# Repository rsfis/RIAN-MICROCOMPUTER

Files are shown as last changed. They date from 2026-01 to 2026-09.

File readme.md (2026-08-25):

<h1 align="center">
  Fiscion Razor32
</h1>
<h3 align="center">
  A Mini Foldable OldStyle Computer
</h3>

<h3 align="center">
  Being only 14x6x5cm, Razor32 is a complete computer with Firmware, OS and Apps.
</h3>

## Features
- Powered by ESP32 S3 Chip with 8mb RAM and 16mb Flash
- Embedded TFT Screen
- 30 keys Matricial Keyboard. Each key has X and Y push up output
- 3000mah Rechargeable Battery
- Foldable Case Easy and Light to Carry
- USB C charging port
- Easy to assemble
- Custom Firmware and OS
- Runs LUA for Apps
- Easy to create your own apps in a Inside IDE and share them within a local network

## Case
Designed using Blender, the Case comes with 4 parts: The lower box, upper box, hinges and screws. Made using PLA material.
showcase
showcase2

## PCB
The PCBs were made using KiCad. The board contains the sockets for esp32 and screen and a 3x10 matricial keyboard using push buttons.


F.Cu

In.1.Cu

In.2.Cu

B.Cu

3D render front


3D render back



Schematic


#### External Wiring Diagram
wiring diagram

## BOM
|FIELD1|Designator |Quantity|Comment |Link |ENTIRE PRICE WITH FREIGHT AND TAXES:|FIELD7|FIELD8|FIELD9|
|---|---|---|---|---|---|---|---|---|
|1 |TFT Screen 3.5" st7796 320*480 ips |1 |TFT Screen 3.5" st7796 320*480 ips Touch |https://pt.aliexpress.com/item/1005005995931721.html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 |R$ 90,84 | | | |
|2 |ESP32 S3 8mb PSRAM 16mb Flash |1 |ESP32-S3-DevKitC-1 |https://pt.aliexpress.com/item/1005007215982839.html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 |R$ 63,38 | | | |
|3 |Aliexpress parts |1 |Pin Headers 1x15 and 1x6; Flat Cable Socket Bottom Connector 14pins; Screws M3x6mm Allen; Push Buttons 6x6x5mm|(Cart image at repo: cart/aliexpress.png) |R$ 129,76 | | | |
|4 |3D Print |2 |3D Print Case |~ |~ | | | |
|5 |PCB |5 |PCB Manufacture Process |~ |$36,35 | | |PRICE |
|6 |Battery 3.7v 3000mah |1 |Battery 3000mah 3.7v |https://www.mercadolivre.com.br/1-unidade-505573-2-fios-3000mah-37v-5mm-x-55mm-x-73mm/p/MLB2081347995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 |$12,00 | |R$ |552,13|
|7 |Battery Charger Module and Step Up Conversor|1 |Battery Charger Module and Step Up 3.7v to 5v Conversor |https://www.mercadolivre.com.br/carregador-bateria-de-litio-5v-2a-conversor-step-up-usb-c/p/MLB2071876811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|$3,42 | |USD |106,59|

## Keyboard Keys Organization
q w e r t y u i o p

a s d f g h j k l B

z x c v b S n m f E

1 2 3 4 5 6 7 8 9 0

+ - % < > ? & ! ( )

/ * = " _ ; . , f Sh

ESC F1 F2 F3 F4 F5 F6 F7 F8 F9

{    }  @ :  [  ]  

|    \  ' -  HOME

## OS and APPS
The OS is the RazorOS, made using ArduinoIDE, LovyanGFX and LUA Interpreter.

The OS itself is programmed in C++ using Arduino IDE, with own firmware. The OS has:
- Home Page with a Desktop area
- Control Panel for Rapid Settings
- Users
- Clock
- Settings
- Task Manager
- Notifications
- Watchdog
- Terminal in LUA

The apps are made in LUA. Apps will create a LUA Virtual Machine to execute the code directly in the processor using various C++ External Functions. 

Using the Text Editor, you will also be able to create your own apps to Razor32 and control everything.

Planned Apps:
- Internet Browser Based on Text (Lynx)
- File Sender

- Text Editor
- Calculator
- To-do
- Calendar
- PDF Viewer
- Excel Like

- Tetris
- Snake

- Scanner Wifi
- Terminal Serial
- Packet Logger

OS and Firmware are still being programmed. For now, RazorOS already has basic drawing and OS functions and Lua VM implemented.

## Cart
jlc
aliexpress

## Getting Started
### How to flash the ESP32:
- Install ArduinoIDE
- Install the following libraries:
-- LovyanGFX, by lovyan03
-- ArduinoJSON, by BenoitBlanchon
- Install the following Board Managers:
-- esp32, by Espressif Systems
-- Select the COM and board 4D Systems gen4-ESP32 Modules (ESP32-S3)
### Extract the files from /firmware/MicroSD Backup.rar
- Copy the files from /firmware/MicroSD Backup.rar to the microsd root directory
- Insert the micro sd in the MicroSD socket below the screen

Made for: Hackclub FORGE - https://forge.hackclub.com/projects/457

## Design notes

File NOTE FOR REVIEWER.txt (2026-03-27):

The "CAD" was not made in a real CAD software, because I didn't know it was supposed to be. It was made in Blender, so, to provide a .step and CAD file, inside "case" there is a Design.FCStd (.obj imported in CAD).

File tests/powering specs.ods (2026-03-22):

 | ESP32 | TFT SCREEN | TOTAL
ACTIVE CONSUMPTION | 90,00 mA | 95,00 mA | 185,00 mA
SLEEPING CONSUMPTION | 0,24 mA | 10,00 mA | 10,24 mA
 | BATTERY | BATTERY CONVERTED
TENSION | 3,7 V | 5,0 V
CAPACITY | 5000,0 mA | 5000,0 mA
 | ACTIVE | SLEEPING
DURATION (HOURS) | 27,0h | 488,3h
DURATION (DAYS) | 1,1d | 20,3d

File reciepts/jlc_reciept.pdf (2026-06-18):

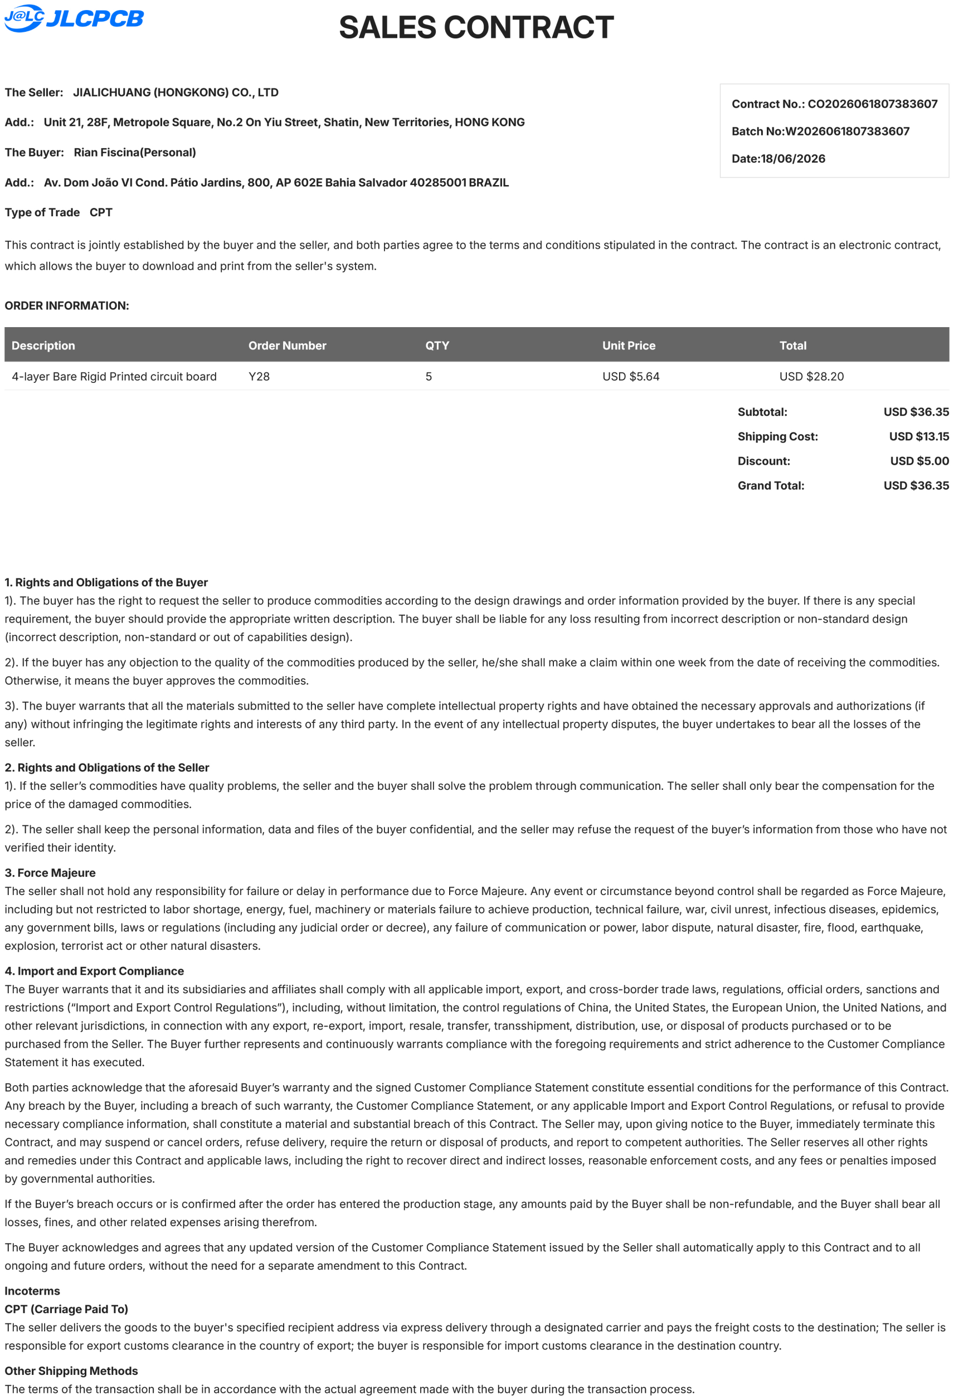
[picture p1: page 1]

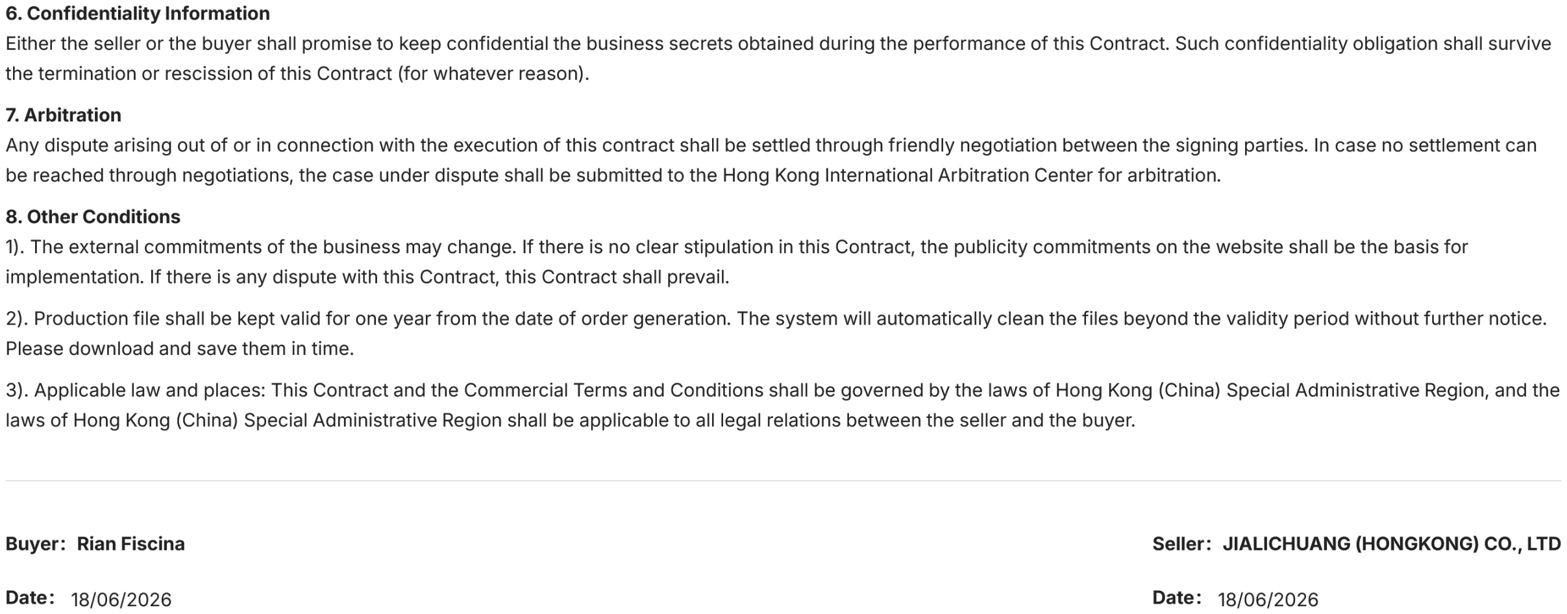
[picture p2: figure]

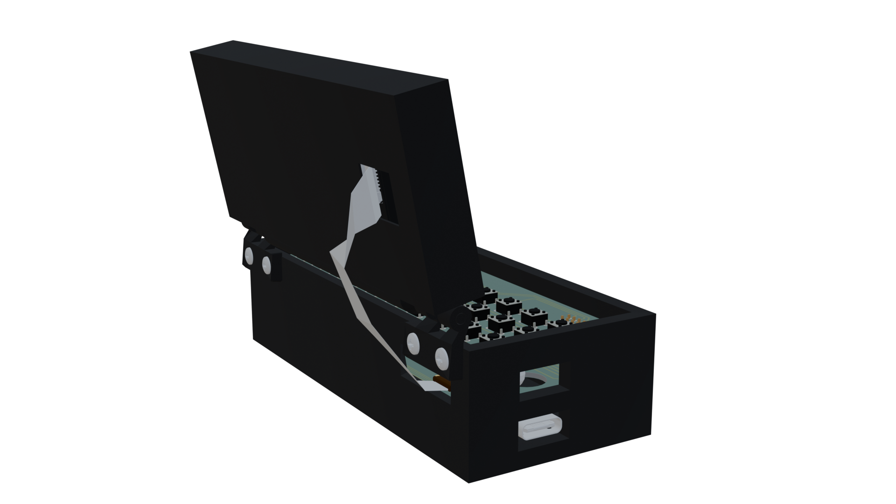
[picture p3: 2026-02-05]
images/showcase2.png

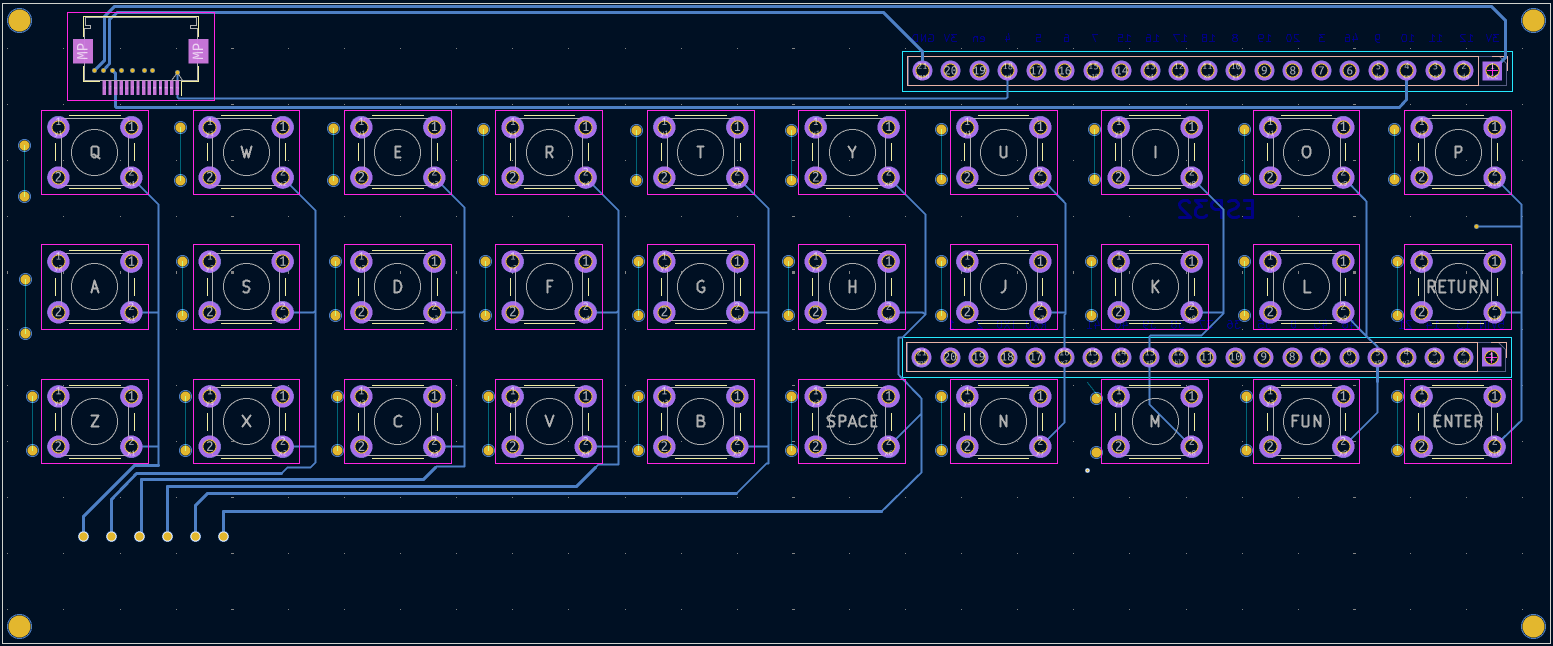
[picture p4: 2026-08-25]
unified pcb/imgs/b_cu.png

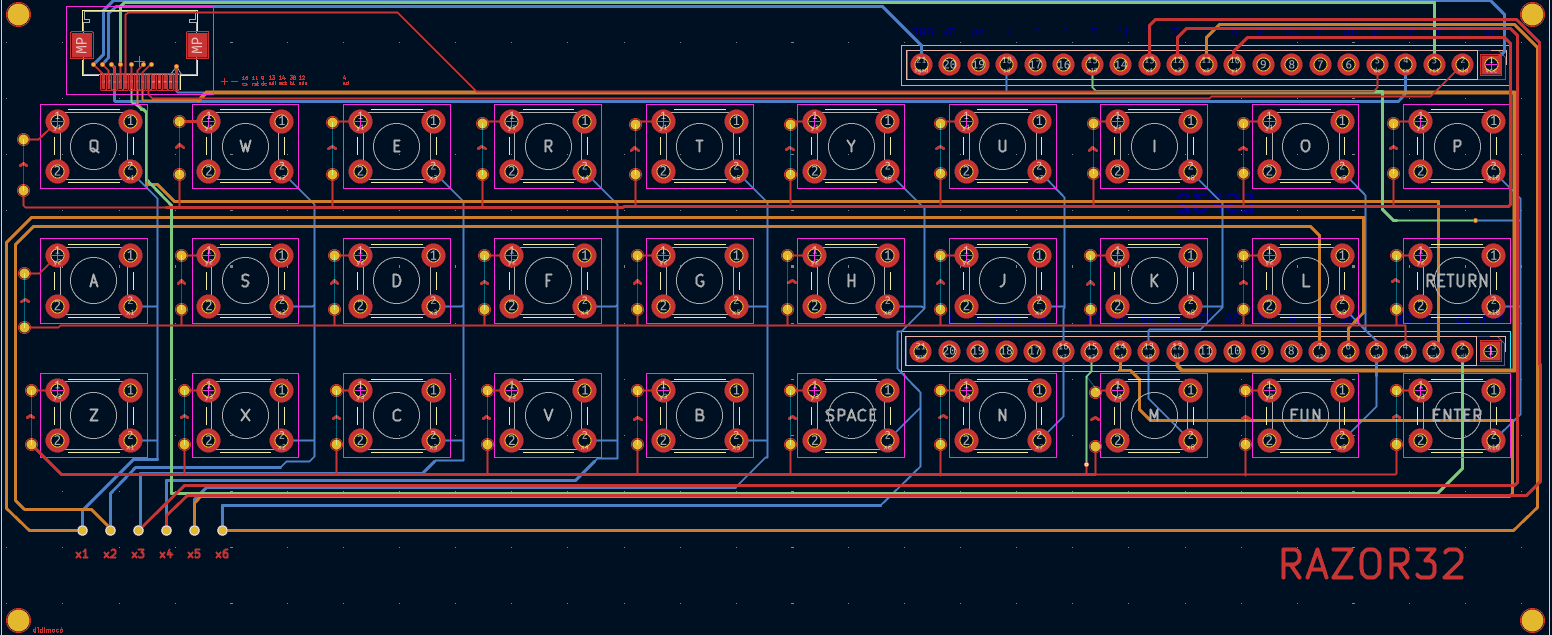
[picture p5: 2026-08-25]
unified pcb/imgs/all.png

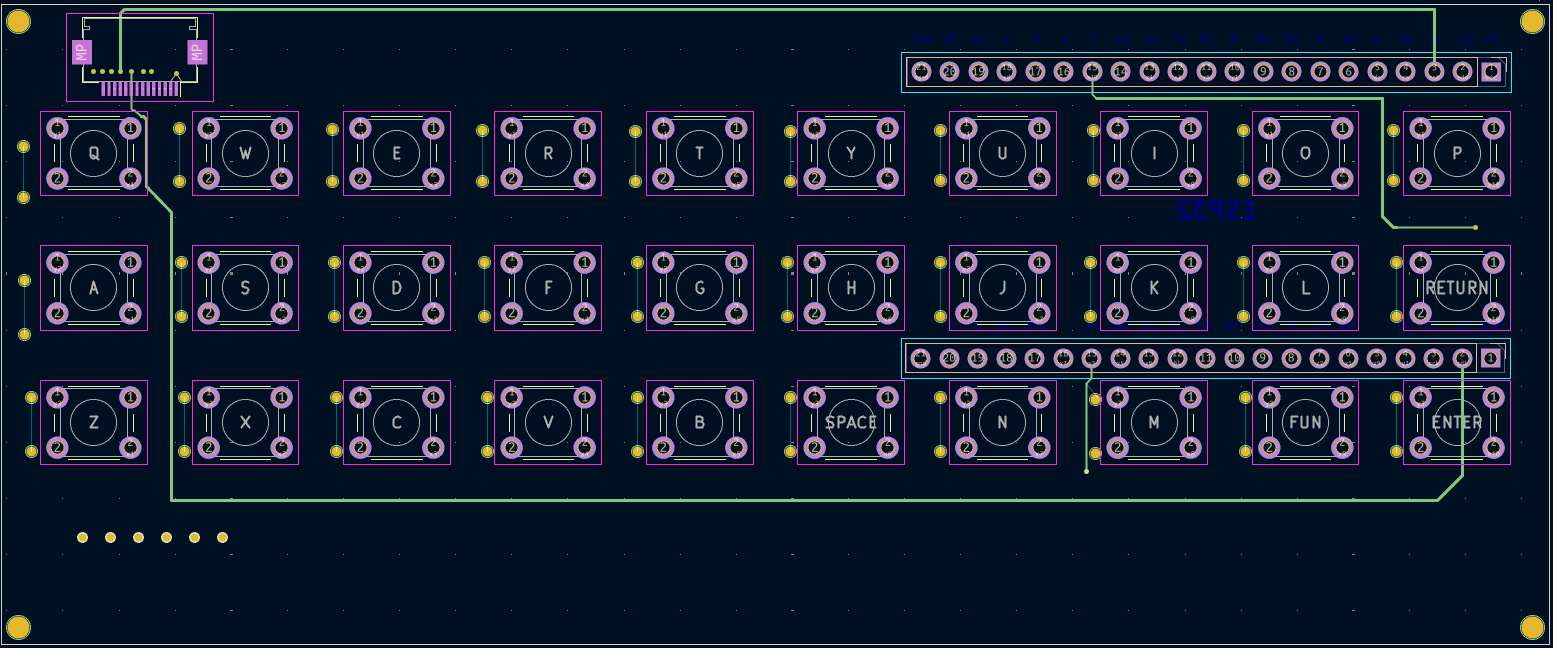
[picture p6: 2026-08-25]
unified pcb/imgs/in1_cu.png

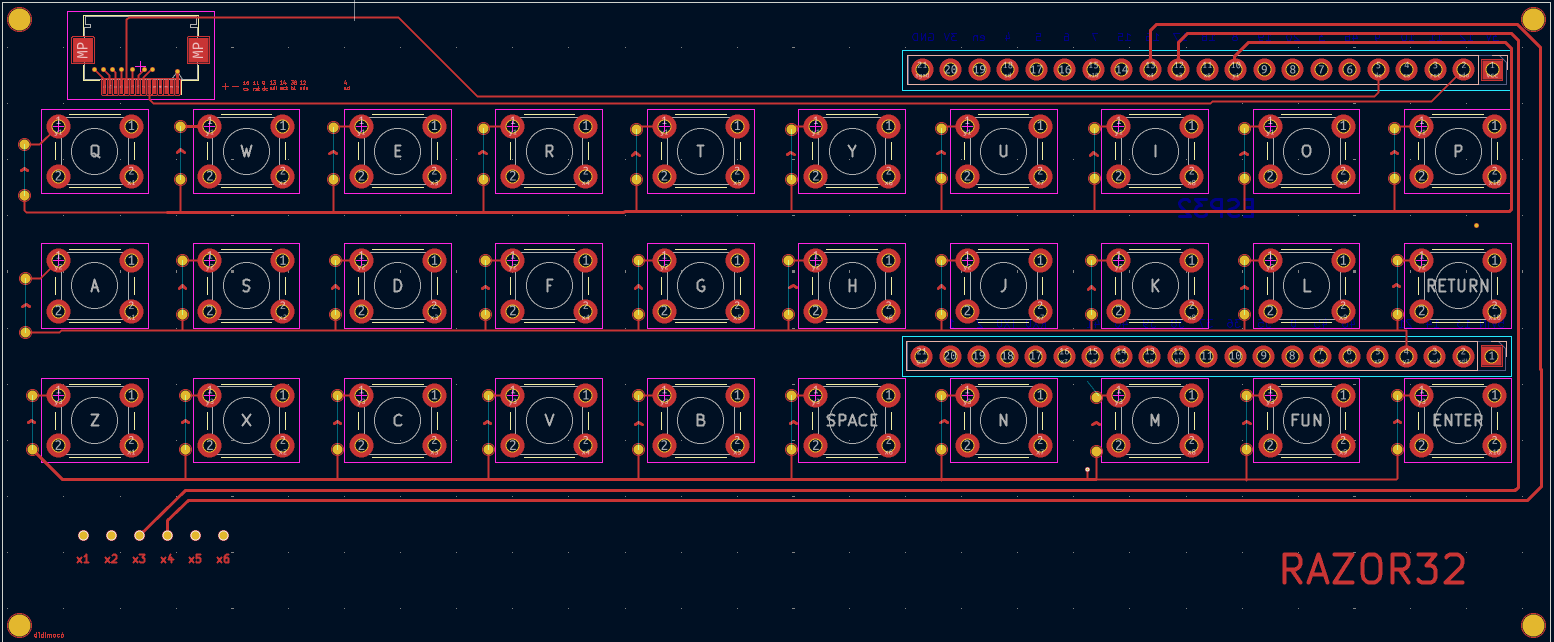
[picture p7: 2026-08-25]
unified pcb/imgs/f_cu.png

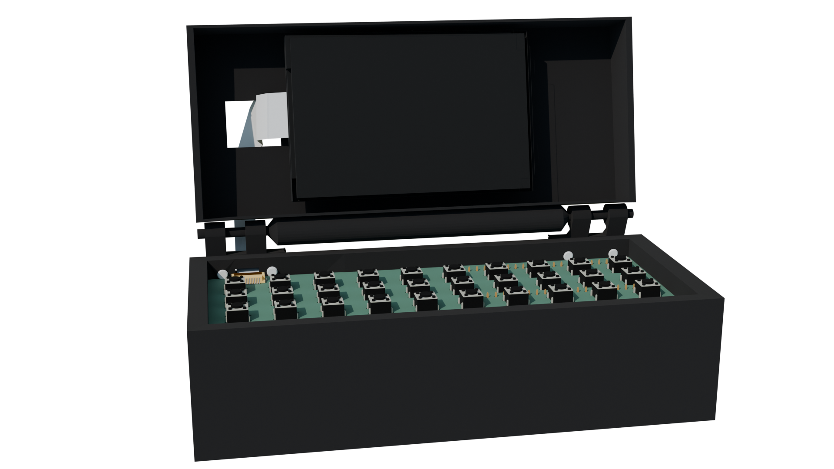
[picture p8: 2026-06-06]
images/showcase.png

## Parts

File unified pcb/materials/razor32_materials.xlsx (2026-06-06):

Id | Designator | Footprint | Quantity | Comment | JLCPCB Part # | Link
1 | a | SW_PUSH_6mm | 1 | SW_PUSH_6mm | C97440 | https://jlcpcb.com/partdetail/ALPSALPINE-SKHHAJA010/C97440
2 | b | SW_PUSH_6mm | 1 | SW_PUSH_6mm | C97440 | https://jlcpcb.com/partdetail/ALPSALPINE-SKHHAJA010/C97440
3 | c | SW_PUSH_6mm | 1 | SW_PUSH_6mm | C97440 | https://jlcpcb.com/partdetail/ALPSALPINE-SKHHAJA010/C97440
4 | d | SW_PUSH_6mm | 1 | SW_PUSH_6mm | C97440 | https://jlcpcb.com/partdetail/ALPSALPINE-SKHHAJA010/C97440
5 | e | SW_PUSH_6mm | 1 | SW_PUSH_6mm | C97440 | https://jlcpcb.com/partdetail/ALPSALPINE-SKHHAJA010/C97440
6 | f | SW_PUSH_6mm | 1 | SW_PUSH_6mm | C97440 | https://jlcpcb.com/partdetail/ALPSALPINE-SKHHAJA010/C97440
7 | g | SW_PUSH_6mm | 1 | SW_PUSH_6mm | C97440 | https://jlcpcb.com/partdetail/ALPSALPINE-SKHHAJA010/C97440
8 | h | SW_PUSH_6mm | 1 | SW_PUSH_6mm | C97440 | https://jlcpcb.com/partdetail/ALPSALPINE-SKHHAJA010/C97440
9 | i | SW_PUSH_6mm | 1 | SW_PUSH_6mm | C97440 | https://jlcpcb.com/partdetail/ALPSALPINE-SKHHAJA010/C97440
10 | j | SW_PUSH_6mm | 1 | SW_PUSH_6mm | C97440 | https://jlcpcb.com/partdetail/ALPSALPINE-SKHHAJA010/C97440
11 | k | SW_PUSH_6mm | 1 | SW_PUSH_6mm | C97440 | https://jlcpcb.com/partdetail/ALPSALPINE-SKHHAJA010/C97440
12 | l | SW_PUSH_6mm | 1 | SW_PUSH_6mm | C97440 | https://jlcpcb.com/partdetail/ALPSALPINE-SKHHAJA010/C97440
13 | m | SW_PUSH_6mm | 1 | SW_PUSH_6mm | C97440 | https://jlcpcb.com/partdetail/ALPSALPINE-SKHHAJA010/C97440
14 | n | SW_PUSH_6mm | 1 | SW_PUSH_6mm | C97440 | https://jlcpcb.com/partdetail/ALPSALPINE-SKHHAJA010/C97440
15 | o | SW_PUSH_6mm | 1 | SW_PUSH_6mm | C97440 | https://jlcpcb.com/partdetail/ALPSALPINE-SKHHAJA010/C97440
16 | p | SW_PUSH_6mm | 1 | SW_PUSH_6mm | C97440 | https://jlcpcb.com/partdetail/ALPSALPINE-SKHHAJA010/C97440
17 | q | SW_PUSH_6mm | 1 | SW_PUSH_6mm | C97440 | https://jlcpcb.com/partdetail/ALPSALPINE-SKHHAJA010/C97440
18 | r | SW_PUSH_6mm | 1 | SW_PUSH_6mm | C97440 | https://jlcpcb.com/partdetail/ALPSALPINE-SKHHAJA010/C97440
19 | s | SW_PUSH_6mm | 1 | SW_PUSH_6mm | C97440 | https://jlcpcb.com/partdetail/ALPSALPINE-SKHHAJA010/C97440
20 | t | SW_PUSH_6mm | 1 | SW_PUSH_6mm | C97440 | https://jlcpcb.com/partdetail/ALPSALPINE-SKHHAJA010/C97440
21 | u | SW_PUSH_6mm | 1 | SW_PUSH_6mm | C97440 | https://jlcpcb.com/partdetail/ALPSALPINE-SKHHAJA010/C97440
22 | v | SW_PUSH_6mm | 1 | SW_PUSH_6mm | C97440 | https://jlcpcb.com/partdetail/ALPSALPINE-SKHHAJA010/C97440
23 | w | SW_PUSH_6mm | 1 | SW_PUSH_6mm | C97440 | https://jlcpcb.com/partdetail/ALPSALPINE-SKHHAJA010/C97440
24 | x | SW_PUSH_6mm | 1 | SW_PUSH_6mm | C97440 | https://jlcpcb.com/partdetail/ALPSALPINE-SKHHAJA010/C97440
25 | y | SW_PUSH_6mm | 1 | SW_PUSH_6mm | C97440 | https://jlcpcb.com/partdetail/ALPSALPINE-SKHHAJA010/C97440
26 | z | SW_PUSH_6mm | 1 | SW_PUSH_6mm | C97440 | https://jlcpcb.com/partdetail/ALPSALPINE-SKHHAJA010/C97440
27 | ret | SW_PUSH_6mm | 1 | SW_PUSH_6mm | C97440 | https://jlcpcb.com/partdetail/ALPSALPINE-SKHHAJA010/C97440
28 | enter | SW_PUSH_6mm | 1 | SW_PUSH_6mm | C97440 | https://jlcpcb.com/partdetail/ALPSALPINE-SKHHAJA010/C97440
29 | fun | SW_PUSH_6mm | 1 | SW_PUSH_6mm | C97440 | https://jlcpcb.com/partdetail/ALPSALPINE-SKHHAJA010/C97440
30 | space | SW_PUSH_6mm | 1 | SW_PUSH_6mm | C97440 | https://jlcpcb.com/partdetail/ALPSALPINE-SKHHAJA010/C97440
31 | ESP32PinSocket_1 | PinSocket_1x21_P2.54mm_Vertical | 1 | PinSocket_1x21_P2.54mm_Vertical | C2883738 | https://jlcpcb.com/partdetail/XKBConnection-X6511FV_21C85D32/C2883738
32 | ESP32PinSocket_2 | PinSocket_1x21_P2.54mm_Vertical | 1 | PinSocket_1x21_P2.54mm_Vertical | C2883738 | https://jlcpcb.com/partdetail/XKBConnection-X6511FV_21C85D32/C2883738
33 | FlatCableSocket | Hirose_FH12-14S-0.5SH_1x14-1MP_P0.50mm_Horizontal | 1 | Hirose_FH12-14S-0.5SH_1x14-1MP_P0.50mm_Horizontal | C5378715 | https://jlcpcb.com/partdetail/HRS_Hirose-FH12_14S_0_5SH_55/C5378715

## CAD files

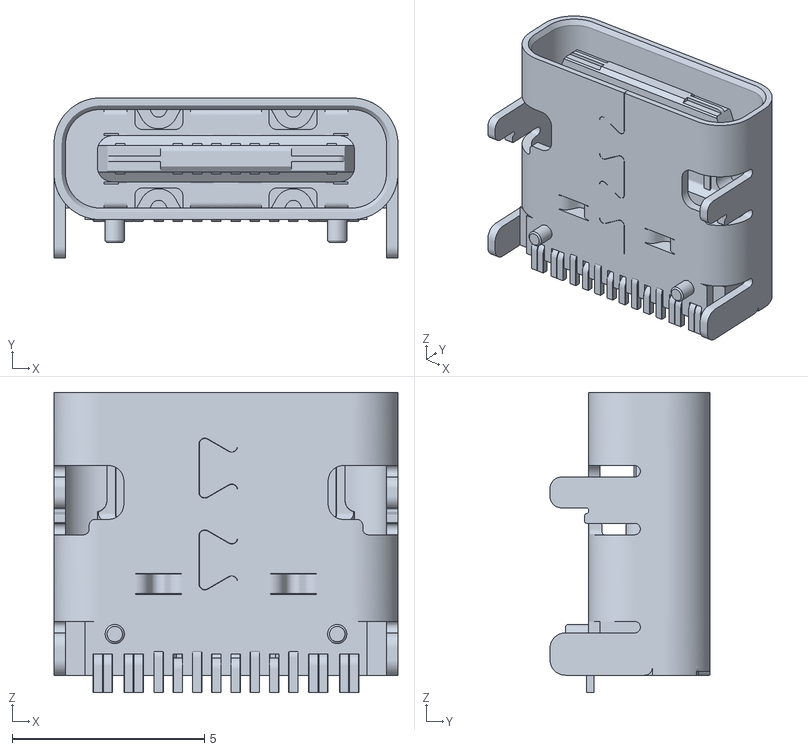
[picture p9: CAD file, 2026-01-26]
case/everything/USB C full.stl
8.94 x 4.16 x 7.80

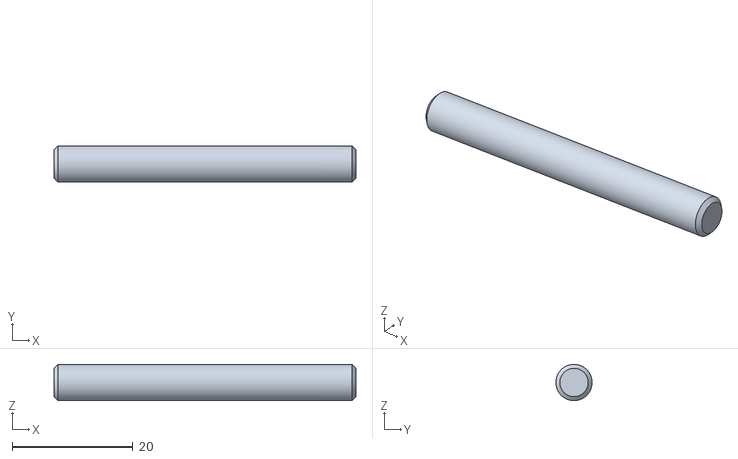
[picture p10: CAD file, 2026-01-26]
case/everything/hinge/hinge3.stl
50.0 x 6.00 x 6.00

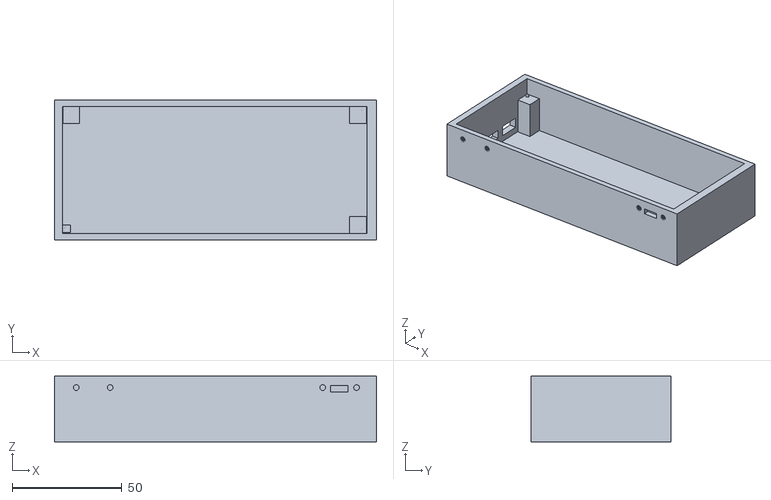
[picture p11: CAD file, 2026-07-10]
case/stl_to_print/Box_Lower.stl
146.9 x 63.7 x 30.1

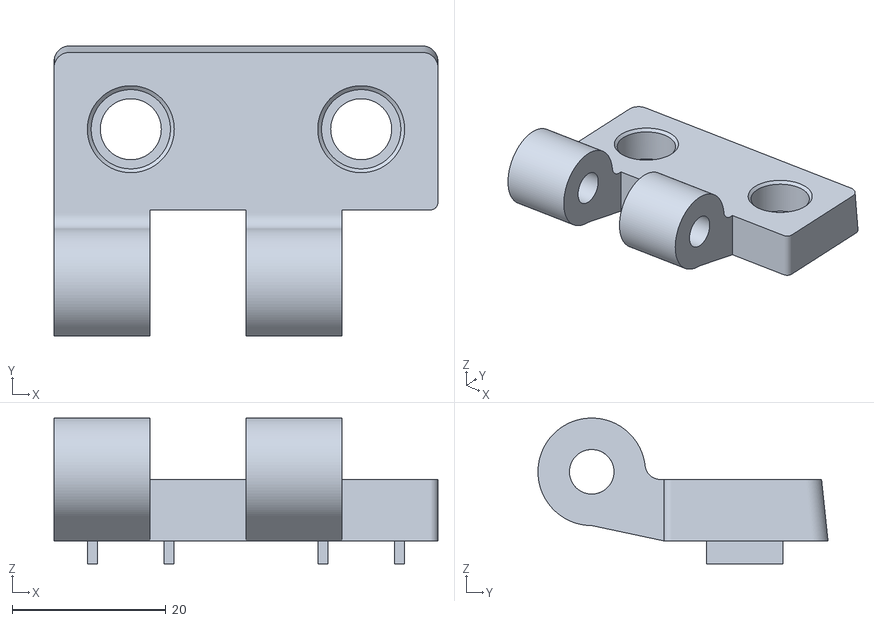
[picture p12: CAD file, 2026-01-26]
case/everything/hinge/hinge2.stl
50.0 x 37.8 x 19.0

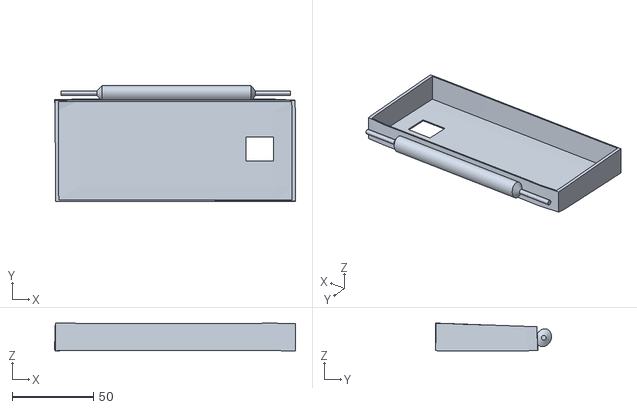
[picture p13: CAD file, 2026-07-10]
case/stl_to_print/Box_Upper.stl
148.1 x 71.3 x 17.0

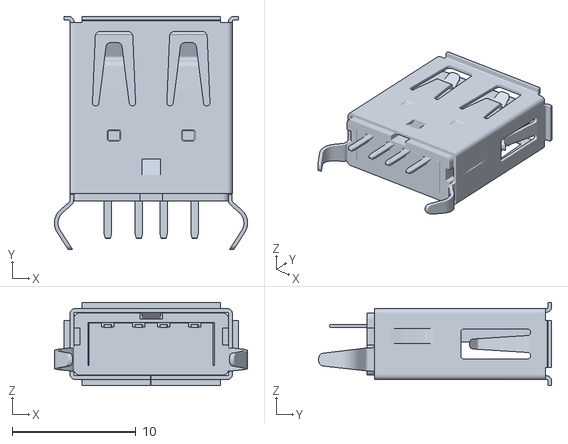
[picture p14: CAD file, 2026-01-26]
case/everything/USB-A1VSXX.stl
15.6 x 18.8 x 6.72

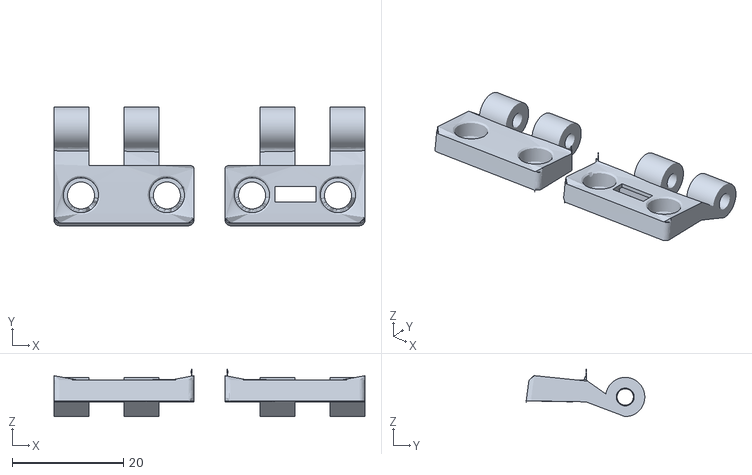
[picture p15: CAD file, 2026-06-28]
case/stl_to_print/Hinges.stl
55.9 x 21.3 x 8.48

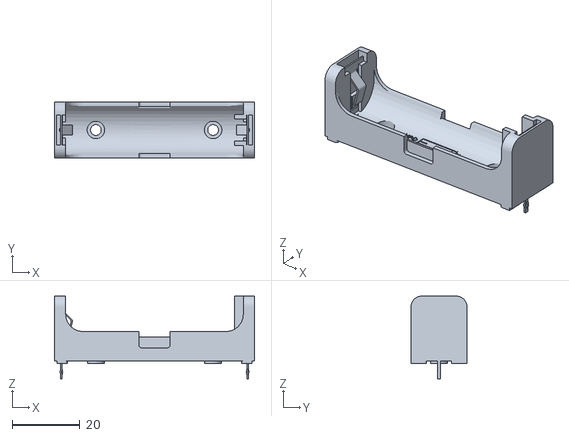
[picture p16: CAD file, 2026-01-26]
case/everything/battery holder.STL
58.9 x 16.5 x 24.4

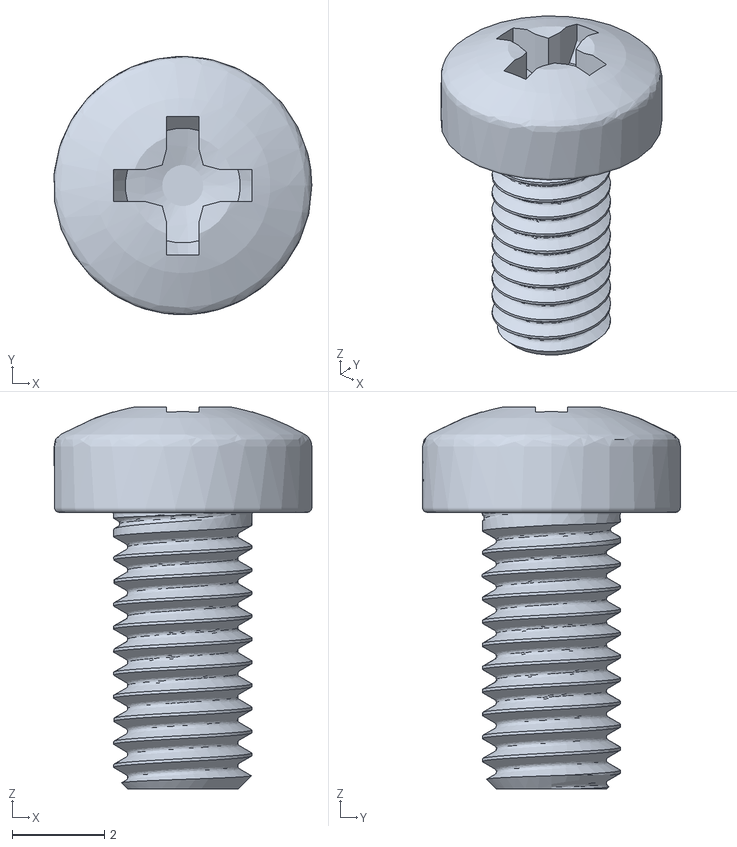
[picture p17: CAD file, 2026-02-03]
case/everything/screw.stl
5.59 x 5.59 x 8.28

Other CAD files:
case/design-before-applies.blend
case/design.blend
case/stl_to_print/blender/box_lower.blend
case/stl_to_print/blender/box_upper.blend
case/stl_to_print/blender/hinges.blend

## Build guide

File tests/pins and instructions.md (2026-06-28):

#### SCREEN:
##### VCC -> 3.3 or 5.5v
##### GND -> GND
##### CS -> 10
##### RST -> 11
##### RS/DC -> 9
##### SDI<MOSI> -> 13
##### SCK/SCLK -> 14
##### BLACKLIGHT -> 38
##### SDO<MISO> -> 12
##### ...
##### ...
##### ...
##### ...
##### SD\_CS -> 4

#### KEYBOARD
##### y1   9
##### y2   21
##### y3   41
##### x1   48
##### x2   45
##### x3   17
##### x4   16
##### x5   40
##### x6   18
##### x7   42
##### x8   39
##### x9   47
##### x10  46

#### *Do not excede 80mhz!*

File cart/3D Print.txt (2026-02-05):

The 3D print will be made by Jay, from PrintLegion, from the USA
The estimate freight is 18$

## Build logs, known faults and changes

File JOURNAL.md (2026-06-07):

# 2026-06-07: Solved new unified board DRC isssues, Prices and Nets

**Total time spent: 2.07 hours**

During these 2 days, I've been solving the board's DRC errors (Nets, unconnected traces and this king of things) and attaching nets to the traces to be more organized.
I also fixed the prices, cuz they were too high.
First: Removed PCBA. Im handsoldering everything to learn.
Second: Searched the components at aliexpress to reduce costs
Third: Removed the powerbank costs to hackclub. The company won't pay for the powerbank.

Lapses at:
https://lapse.hackclub.com/timelapse/hVn5yxIEUJEf
https://lapse.hackclub.com/timelapse/W5_5n5CTUVG4





# 2026-06-05: Unified the 2 PCBS

**Total time spent: 2 hours**

During these 2 days, as the reviewer asked, I unified the 2 PCBS into one PCB.

Before: 2 pcbs with 2 layers
After: 1 pcb with 4 layers

Im pretty happy with the result.

This decision was important, because this way, the project is now pretty thinner, since the second floor is gone, and everything would cost less.

First, I put all components into another pcb sketch, and started trying to fit everything.
I wanted to make a 2 layer unified pcb, but it just didn't fit, because there is too many tracks.
So, I added 2 more inner tracks and started routing just like the other pcbs.

This is the final routing and displacement:

F.Cu

In.1.Cu

In.2.Cu

B.Cu

3D render front

3D render back


https://lapse.hackclub.com/timelapse/RG1gdj3PHxtt

# 5/18/2026 - Transference from Blueprint to Forge program

**Total time spent: 0.1 hours**

Time spent: 0.1h  

After more than 2 months of waiting, I decided to transfer Blueprint to Forge.

Now, Im going to wait anxiously to the final review.



# 2/27/2026 - System's Kernel and Tests

**Total time spent: 12.0h**

Time spent: 12.0h

During 4 days (From 4 days ago to today), I've been developing the OS Kernel.
I've spent great 12 hours developing the kernel main functions and folder structure.

The kernel now starts screen, starts sd module, loads boot configs, creates screen frame, loads general configs, synchronize time using wifi to obtain real life time and set it to the RTC and then turns off wifi to save energy, loads user, starts first lua vm (OS Graphic Interface).

OS functions:

Display_ClearScreen, Display_UpdateScreen, OS_GetFreeMemory, OS_GetMemorySize, OS_GetFreeHeapMemory, OS_GetHeapMemorySize, OS_GetCPUTemperature, OS_GetTime:toString("%d/%m/%Y - %H:%M:%S"), OS_GetLuaVMHeapMemoryUsage, OS_GetUserUsername, OS_GetUserPassword

Furthermore, I've made the Sprite exported structure and exported lua variable type and so with Fonts.
This is a simple example lua code of how the system is working:
```
local user_login_bg = Sprite("/sys/img/user_login_bg.png", 480, 320)
local gothambold_font = Font("/sys/fonts/Gotham Bold.bin")

-- FPS
local fps = 0
local frameCount = 0
local lastTime = os.clock()

function loop()
   while true do
      local currentTime = os.clock()
      frameCount = frameCount + 1

      -- Atualiza FPS a cada 1 segundo
      if currentTime - lastTime >= 1 then
         collectgarbage("collect")
         fps = frameCount
         frameCount = 0
         lastTime = currentTime
         --print("FPS:", fps)
         --print("Temperature: ", OS_GetCPUTemperature())
         --print("Free Memory: ", OS_GetFreeHeapMemory())
         --print("Memory Size: ", OS_GetMemorySize())
         --print("RTC: ", OS_GetTime():toString("%d/%m/%Y - %H:%M:%S"))
         --print("Lua Heap Memory Usage: ", OS_GetLuaVMHeapMemoryUsage())
      end

      Display_ClearScreen()

      user_login_bg:draw(0, 0)
      gothambold_font:drawString(OS_GetUserUsername(), 148, 150, 20, 255, 255, 255)

      Display_UpdateScreen()
   end
end

function start()
   loop()
end

start()
endProgram()

```

Images are always in .png, supported transparency, and fonts are always in .bin.
The fonts are converted from ttf to binary files using a python script avaliable on github.

The most difficult part was the Lua VM memory management: In the beginning, there was a big memory leak in LUA VMs. The solution was to call every second collectgarbage("collect").
And also: the luaHeapUsed variable was being miscounted, causing a memory leak.

Here is the OS booting and start page:
WhatsApp Image 2026-02-27 at 21.43.36(1)
WhatsApp Image 2026-02-27 at 21.43.36

# 2/12/2026 - Powering

**Total time spent: 0.3h**

Time spent: 0.3h

Today I finally found the perfect powering system to this project: Futurizta Power Bank 5000mah Mini.

This power bank has 5000mah (Battery would last so longer than if I've bought a AAA battery), so it would last 27h. And with the WIFI on: 14.5h.

In addition, it is so tiny being only 7.5x3.5x2cm, fitting perfectly inside the computer.

This project is gonna be really fat. The lower part will be 4cm tall.

Screenshot_20260212_091511_Opera GX

So, the powering chart is like this now:


# 2/10/2026 - Powering Issues

**Total time spent: 0.3h**

Time spent: 0.3h

Today I've finally recieved my stickers, and they are so cute!

Loved the processor one!!





To frustrate a little bit the day, though, the battery holders didn't work. It just doesn't charge and neither transfers the electricity to the esp32.
To solve that, I will use a power bank that must have 2 USBS (one for charging, and one for output) and a powering on/off button.
I will use a power bank module to prioritize safety, reduce development risk, and keep the project scope focused on PCB design, firmware, and system integration. The power bank provides built-in protection and regulated output.

# 2/7/2026 - OS Design

**Total time spent: 0.5h**

Time spent: 0.5h  

In an hour, I made the OS design and pages in paint.
I want the design to be a little Linux Like, kinda cozy, and easy to use. It will work with an arrow system. With WASD you control where your "cursor" is, like game consoles.

Starting:


Login:


Home Page:


# 2/6/2026 - README, Github, Name and Notes for the reviewer

**Total time spent: 1.0h**

Time spent: 1.0h

During these 2 days, I've been writing the README and configuring the Github Repo.

The README is already avaliable on Github.

I also changed the project's name, to be more, shocking...

Added some notes for the reviewer about why 2 computers and the lack of a correct .step (Current is 4gb).



Furthermore, I made the wiring diagram for parts out of the pcb.
wiring diagram

# 2/3/2026 - Case Fixes and More PCB Quotings

**Total time spent: 2.0h**

Time spent: 2.0h

During these days, I've added screw holes to my case, and discovered that the JLCPCB don't have the part I need (Pinheader Pitch 2.54mm 8mm height), so I'm going to buy this part from AliExpress, and solder it by myself with a borrowed Solding Station from the theater lights guy.

I also converted the .blend into a .step file. It had a some of errors and convertion isn't precise, but ok. It is 4gb...

In addition, to the 3D prints, I found a guy that prints inside Blueprint (I forgot the program name). And he just ask for the shipping price and fillament.

imagem_2026-02-03_190743825

imagem_2026-02-03_190820493

# 1/31/2026 - First Firmware steps and OS

**Total time spent: 6.0h**

Time spent: 6.0h

Today, I've researched some ways to run the Firmware, multitasking and apps.

So, the problem was about the apps: How the system would run multiple apps with open software and that wouldn't depend on just the base firmware and save states, I mean, if I put every app inside the firmware (.ino), the apps wouldn't be updateable easily. Everything would be linked in a way that: If a software breaks, all the system breaks, and I would have to compile the ENTIRE SKETCH again and again.

To solve it, I decided to run a Lua interpreter within Esp32.

This will allow me to create: The bios, firmware, OS and apps runner separately from the apps themselves.

The firmware and OS will be created apart in a .ino sketch, and the apps will have their own folder inside the SD Card and their own folder structure. Generally containing fonts, images, config json, .lua scripting files.

The OS job will only be read the lua script and interpret it.

There will be a ton of external functions which could be used to create the apps, such as: File functions, Drawing, Math, OS management (Configs, restart, shutdown, close app, etc). The definitions and instructions controlled and set by the C++ sketch (Firmware).

This is the base of the firmware. So far it has only the screen and sd init, interpreter starter and one external function: endProgram() to end the VM.

imagem_2026-01-31_182833809

# 1/30/2026 - Tracked Prices

**Total time spent: 2.0h**

Time spent: 2.0h

During these 2 days of work, I've made some work on the PCB -fixed the tracks that were not straight[tortas] (idk how to say it in english) and revised all the tracks- and routed where I should manufacture them.

I started calling a lot of local factories, but they were so expensive.

So, I will manufacture everything with JLCPCB. I've added the general board to my cart, but 1 component for the keyboard were in inventory shortage, so I pre-ordered by 5ish dollars the Pin Header I need.

The problem when quoting on JLCPCB was that my BOM was really messed up, and I had to redo it using the JLCPCB pattern. This took me a lot of time.
And the other problem was that I had to search for the components, and it took so much time. The time consuming one were the pin headers and pin sockets. Some were not avaliable, so I had to make a pre-order.

Everything will cost approximately 700 reais (5 general boards and 5 keyboards. 2 assembled).

Plus the 3D print for the case will cost ~18 dollars (Two PCs) (JayG from HackClub Printing Stuff).

The screen: ~140 reais (paid by me)
The ESP32: ~90 reais (paid by me)

imagem_2026-01-30_211424497

# 1/26/2026 - Design Edited and More Powering Tests

**Total time spent: 1.0h**

Time spent: 1.0h  

Today I've made some changes on the design. Added a USB port, added the esp32 on the board, modified the hinges to be more tight to the hinge "connector).

I also tested the light sleep and tft sleep functions, reset using software and googled about power consumption. Everything now is schematized.

I made a chart about the powering:
imagem_2026-01-26_164341373
Powering looks decent and so the battery duration.

# 1/25/2026 - Design

**Total time spent: 4.0h_**

_Time spent: 4.0h_  

Today I've made the computer design  using Blender. Since this was my first time working on Blender, it was pretty hard to get the shortcuts and become fast on it.
The most difficult part was making the upper lid, because it needs to have some space on the hinge to turn. The 3D printer makes everything more fat (3.8h)

Also discovered how I will power it up, charge and power down.

So, for powering I will use a 18650 USB, which transforms an AA battery into a Power Bank. The output is 5V  2A, which seems ok to the setup. I decided to do so, because I can connect an USB-C cable from the output directly to the ESP32, and in my tests, 5V directly from a battery didn't power up everything and the screen backlight was so weak.

To charging up, I will put a USB-C male connected to the input of the battery and connect it to a converter USB-C male to USB-A female. So, there will be a USB-A port ready to plug in and charge everything.

The system will never turn down completely, because this battery holder I ordered doesn't have a switch and I wouldn't be able to cut the powering of the usb-c cable (at least for now).

So, there will be a button in the system to turn off, which will activate the esp32 deep hybernation mode and turn off the screen. Then, when clicking any key on the keyboard's row 5 (tgv row), it will restart and exit hybernation. The only way to turn it completely down, would be letting it run out od battery.





I also made some modifications on the PCB (Cut a hole on the PCB to pass the USB C to charge the ESP32, removed the battery support and added the flat cable socket for screen and reconected tracks to the socket) (0.3h).



# 1/23/2026 - Main PCB

**Total time spent: 4.0h_**

_Time spent: 4.0h_

This one connects everything together: the ESP32, the screen (via a flat cable socket), and the keyboard PCB. I based the connections on what I had already tested on the PCB, which made it a bit faster. The main difficulty was figuring out the placement so everything fits inside the case.

So, basically this PCB has a pin header connector to connect the keyboard, a flat cable socket to connect the screen using a flat cable, and a pin header connector to fit the esp32.

If one of these components get damaged, I can only replace the damaged one, by a new.

I made two separate PCBs instead of one because fitting everything on a single board would be too tight. Having them separate also makes the project more reliable — if one board gets damaged, I can just replace that one without losing the other.

I placed the components based on my protoboard layout and routed the tracks manually. I actually drew the schematic after finishing the PCB, copying from the tracks I had already placed — not the usual order, but it worked.

Power issue
I still haven't figured out how to power the device inside a small case. AA rechargeable batteries at 3.7V are already above what the ESP32 can take directly, and the capacity would probably only last a few minutes anyway. I'm looking into either a step-down module that converts 7.6V to 3.3V, or a battery case with a USB-C output that handles the voltage for me.

Captura de tela 2026-01-24 215628
Captura de tela 2026-01-24 215636

# 1/19/2026 - Keyboard PCB

**Total time spent: 8.0h_**

_Time spent: 8.0h_  

This week I tested the components on the protoboard and its connections again, and I also tested some push buttons, because I had to know how they work.
I discovered that these push buttons work by 2 pins, the left-upper (GND input) and right-lower (RESISTANCE output). So, for 30 keys, I would have to use 30 GPIO pins of the esp32, which wasn't economic. So, I decided to use a matricial keyboard, which is a economic way to use fewer pins. It works just like a screen, where there is a X and Y position. This position determinates which button you press based on a bidimensional matrix, a map.

So, I defined the buttons and its variations:
q w e r t y u i o p
a s d f g h j k l B
z x c v b S n m f E

1 2 3 4 5 6 7 8 9 0
+ - % < > ? & !  (   )
/ *  =  "  _  ;  .  ,  f Sh

ESC F1 F2 F3 F4 F5 F6 F7 F8 F9
{  }  @ :  [ ]  
|  \  '  -  HOME

I used KiCad, which I had never used before, so it took a while to figure out. I made two separate boards.

The biggest challenge here was that the ESP32 doesn't have that many GPIO pins, so I couldn't just dedicate one pin per key. I organized the keys in a matrix — the same idea used in screens, where every pixel has an X and Y position. Each key has its own column and row, and when both are activated at the same time, the firmware knows which key was pressed. This way I use way fewer pins.
I placed the components based on my protoboard layout and routed the tracks manually. I actually drew the schematic after finishing the PCB, copying from the tracks I had already placed — not the usual order, but it worked.

Unfortunately, I had to remake the traces because I wasn't understanding how it worked (I didn't understand networks, and neither I do now).

So, basically this PCB have the push buttons and the pin header connector, which is a lot of pins to connect the keyboard over the main pcb.

Captura de tela 2026-01-24 215701
Captura de tela 2026-01-24 215708

# 1/03/2026 - Screen Testing

**Total time spent: 8.0h_**

_Time spent: 8.0h_  

Breaking my patience with drivers and display (5h)
During these days, I tested the 3.5" TFT screen, with some 3D on it, SD card tests and ESP32 memory using LovyanGFX.

The main problem I had with the screen, was that I was trying to follow the manufacturer manual, but it suggested the library TFT_eSPI, and it didn't matter how much I tried, it didn't work. So, I tried some different libraries, like Arduino_ST76.., and the one that finally worked: LovyanGFX!

At the start, LovyanGFX didn't work. The pins were a little off (I connected some pins wrong and also configured the library wrong. But, I made it work! And here are some tests I made:

Simple Tests: 3h
Images covering the entire screen at great 17.1fps. First, created a frame to store every pixel and then blit the entire frame directly to the screen to increase performance. Then, created a struct called Sprite that creates and loads a sprite. Its Draw function draws the sprite (With transparency) to the frame. It loads .png from the SD Card.

3D cubes rendering using the same principle of the frame, but drawing and calculating each pixel separately. Calculates the camera perspective and each cube's face and vertices position and draw each pixel.

Pre made test for LovyanGFX of its drawing functions


Complex 3D models rendering CPU bound from scratch (22h disconsidered from counting!)
Here I tested the screen making from scratch a 3D models renderer using only the CPU and functions from LovyanGFX.
To do that, I thought I could work with the .glb. But I realised that the ESP32 wouldn't be able to read it because it would be so slow to read and interpret the glb data, and it would be a binary file (more difficult to make the interpreter), so I created a script that converts a .glb model to a cpp header with the texture and vertices. After that, I created a program in ArduinoIDE (the program I'll be using to make everything) that imports some models in RAW .h (Lists of meshes and textures with int and float values) and calculates the perspective, rotation, position, scale and the colour of each pixel in the screen. But it turned out that the colours were messed up and inverted:
IMG-20251025-WA0013
Even if I inverted the LovyanGFX colours setting, it wouldn't work. After, I realised that my colour converter from the normal colours to RGB565 colours was wrong.
When I changed the orders: Perfect pixels and render.
Screenshot_20260304_143709_WhatsApp
The code is avaliable on github at tests/3d_models/3d_models.ino

# 1/03/2026 - The idea

**Total time spent: 1.0h_**

_Time spent: 1.0h_  

Hi! This is the first journal entry of the Rian's MicroComputer.
This is my first hardware project, and it was in these 3 weeks that I learned how to use KiCad and 3D rendering (thats why it has 12h only for pcbs and 22h only for 3D rendering from scratch using pixels, no 3D lib behind it)

I always was addicted to computers, mainly in how they work. Recently I've been addicted to OS's and PCBs. Then, I wanted so much to do something that unified these 2 addictions. So, from 3rd January to 5th January, I had an idea: what if I made my own computer?

I started studying my idea, and tried to create the first image on my head. I wanted it to be like a Nintendo 3DS - portable, foldable, small, but instead of an analog stick, it would have a keyboard.

I knew that I would need a screen and a processor, but which?
For the processor, I thought about an Arduino micro controller, and for the screen, something that communicates with it using GPIO pins: TFT Screens! So I bought one 3.5" screen at Aliexpress. But when I tested the arduino I already had with the screen, it was SO SLOW. Then, I thought: Why not a Raspberry PI? And the answer is: I want to make the Operational System too! And it is so complicated to do with a real micro computer. So, lets simplify things: I found an Arduino, but more powerful, stronger and smaller: ESP32-S3.
With the ESP32-S3 I found, I would have the great amount of 16mb flash, 8mb RAM, and 240mhz (While arduino only had 2mb flash, a few kb of RAM and 16mhz).
I bought the ESP32 and tested it with the screen, and this is what I realised... in the next journal.



References: 
LovyanGFX Graphics Lib Docs I created: [docs](/user-attachments/blobs/proxy/eyJfcmFpbHMiOnsiZGF0YSI6MTI4MTgwLCJwdXIiOiJibG9iX2lkIn19--34296b57b84e30e53a206c20e1219ba0597a7385/docs.txt)
TFT Screen Pins: [pins and instructions](/user-attachments/blobs/proxy/eyJfcmFpbHMiOnsiZGF0YSI6MTI4MTgxLCJwdXIiOiJibG9iX2lkIn19--d9cf887b7b4b8194627fff10a0912c5fef83ded2/pins%20and%20instructions.txt)
TFT Screen datasheet: [3.5inch_SPI_Module_MSP3525_MSP3526_User_Manual_EN](/user-attachments/blobs/proxy/eyJfcmFpbHMiOnsiZGF0YSI6MTI4MjAwLCJwdXIiOiJibG9iX2lkIn19--e6029fc0dd42921700cebb05dfc5681f751da224/3.5inch_SPI_Module_MSP3525_MSP3526_User_Manual_EN.pdf)
ESP32 S3 datasheet: [esp32-s3_datasheet_en](/user-attachments/blobs/proxy/eyJfcmFpbHMiOnsiZGF0YSI6MTI4MTgzLCJwdXIiOiJibG9iX2lkIn19--8f73b24e2fe7c50b8681c89f8a55815ece124108/esp32-s3_datasheet_en.pdf)
KiCad tutorial: https://www.youtube.com/watch?v=mmhareh99P8
Blender tutorial: https://www.youtube.com/watch?v=peSv5IT5Ve4
LovyanGFX tutorial: https://www.youtube.com/watch?v=IPCvQ4o_WP8

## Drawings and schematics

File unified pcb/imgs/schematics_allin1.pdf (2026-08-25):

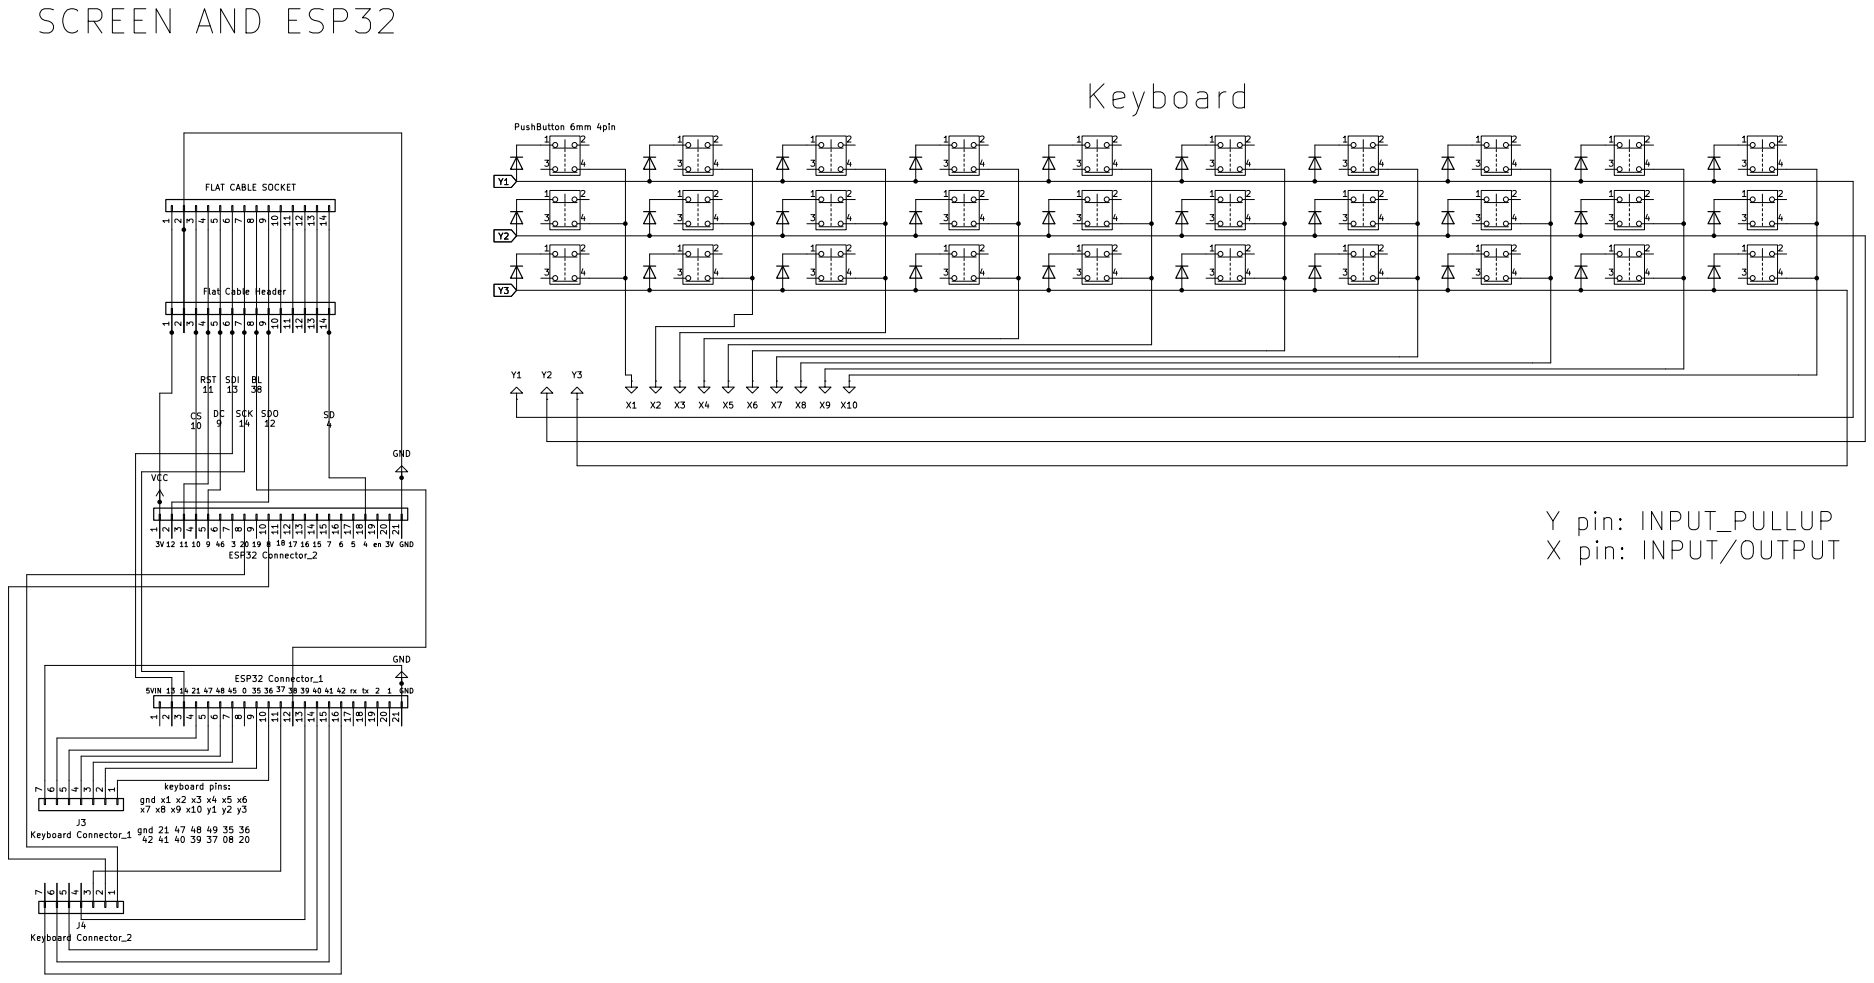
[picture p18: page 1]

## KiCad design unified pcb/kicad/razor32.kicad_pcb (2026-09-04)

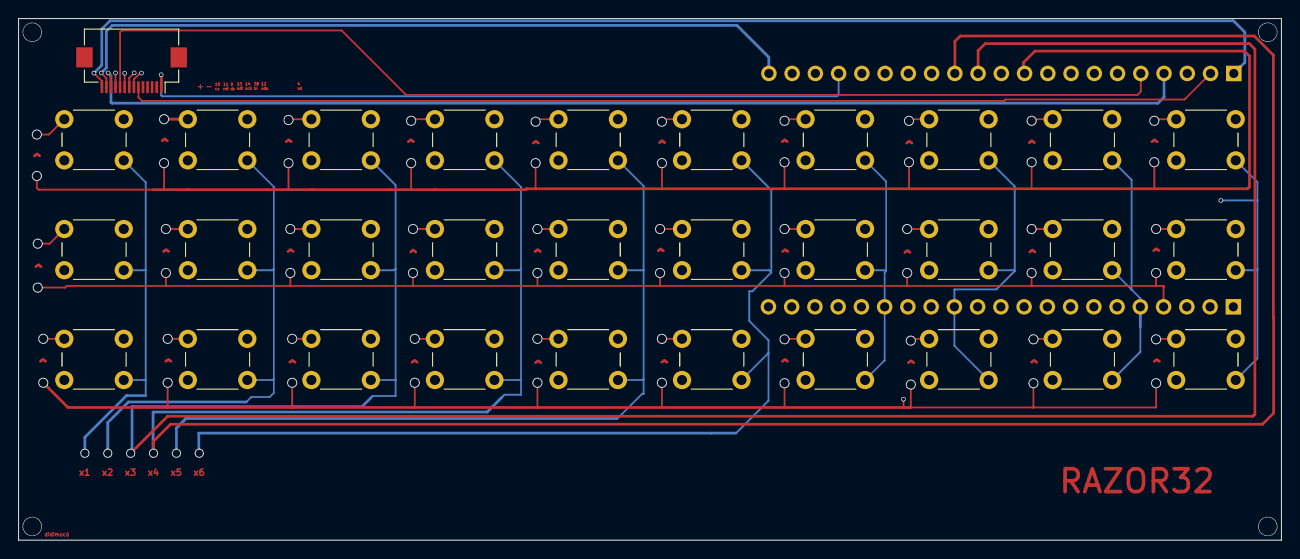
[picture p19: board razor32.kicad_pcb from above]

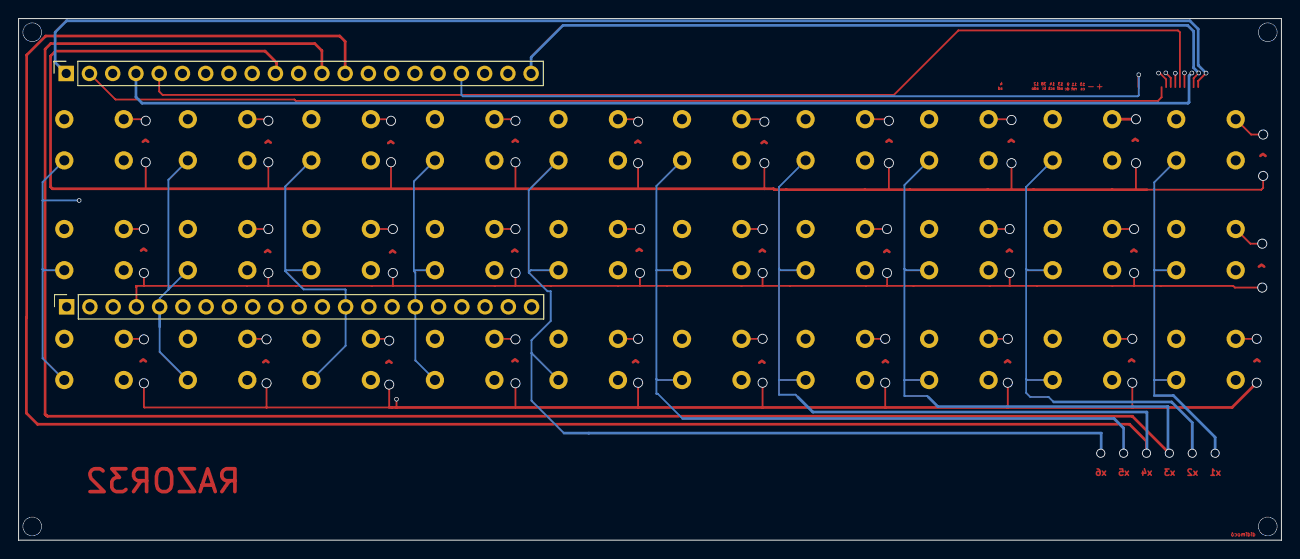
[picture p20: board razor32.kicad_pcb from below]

Board: 4 copper layers, 138.0 x 57.0 mm, 33 parts (2 on the bottom side), 23 nets.

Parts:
ESP32PinSocket_1, ESP32PinSocket_2: PinSocket_1x21_P2.54mm_Vertical
FlatCableSocket: Hirose_FH12-14S-0.5SH_1x14-1MP_P0.50mm_Horizontal
a: SW_PUSH_6mm
b: SW_PUSH_6mm
c: SW_PUSH_6mm
d: SW_PUSH_6mm
e: SW_PUSH_6mm
enter: SW_PUSH_6mm
f: SW_PUSH_6mm
fun: SW_PUSH_6mm
g: SW_PUSH_6mm
h: SW_PUSH_6mm
i: SW_PUSH_6mm
j: SW_PUSH_6mm
k: SW_PUSH_6mm
l: SW_PUSH_6mm
m: SW_PUSH_6mm
n: SW_PUSH_6mm
o: SW_PUSH_6mm
p: SW_PUSH_6mm
q: SW_PUSH_6mm
r: SW_PUSH_6mm
ret: SW_PUSH_6mm
s: SW_PUSH_6mm
space: SW_PUSH_6mm
t: SW_PUSH_6mm
u: SW_PUSH_6mm
v: SW_PUSH_6mm
w: SW_PUSH_6mm
x: SW_PUSH_6mm
y: SW_PUSH_6mm
z: SW_PUSH_6mm

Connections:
bl: ESP32PinSocket_2.12, FlatCableSocket.7
cs: ESP32PinSocket_1.4, FlatCableSocket.12
dc: ESP32PinSocket_1.5, FlatCableSocket.10
rst: ESP32PinSocket_1.3, FlatCableSocket.11
sck: ESP32PinSocket_2.3, FlatCableSocket.8
sd: ESP32PinSocket_1.18, FlatCableSocket.1
sdi: ESP32PinSocket_2.2, FlatCableSocket.9
sdo: ESP32PinSocket_1.2, FlatCableSocket.6
sgnd: ESP32PinSocket_1.21, FlatCableSocket.13
vcc: ESP32PinSocket_1.1, FlatCableSocket.14
x1: ESP32PinSocket_2.6, a.2, q.2, z.2
x2: ESP32PinSocket_2.7, s.2, w.2, x.2
x3: ESP32PinSocket_1.12, c.2, d.2, e.2
x4: ESP32PinSocket_1.13, f.2, r.2, v.2
x5: ESP32PinSocket_2.14, b.2, g.2, t.2
x6: ESP32PinSocket_1.11, h.2, space.2, y.2
x7: ESP32PinSocket_2.16, j.2, n.2, u.2
x8: ESP32PinSocket_2.13, i.2, k.2, m.2
x9: ESP32PinSocket_2.5, fun.2, l.2, o.2
x10: ESP32PinSocket_1.15, enter.2, p.2, ret.2
y1: ESP32PinSocket_1.10, e.1, i.1, o.1, p.1, q.1, r.1, t.1, u.1, w.1, y.1
y2: ESP32PinSocket_2.4, a.1, d.1, f.1, g.1, h.1, j.1, k.1, l.1, ret.1, s.1
y3: ESP32PinSocket_2.15, b.1, c.1, enter.1, fun.1, m.1, n.1, space.1, v.1, x.1, z.1

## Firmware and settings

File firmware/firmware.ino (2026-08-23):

#include <Arduino.h>
#include <esp_heap_caps.h>
#include <esp_task_wdt.h>
#include <LovyanGFX.hpp>
#include <SD.h>
#include <ArduinoJson.h>
#include <WiFi.h>
#include "time.h"

//Keys Pins
//y1   9
//y2   21
//y3   41
//x1   48
//x2   45
//x3   17
//x4   16
//x5   40
//x6   18
//x7   42
//x8   39
//x9   47
//x10  46

#define KERNEL_VERSION "ALPHA 0.2.6"

#define LUA_HEAP_LIMIT (7 * 1024 * 1024)
#define LUA_TASK_STACK 20000

#define SD_CS 4

#define LUA_SPRITE_DEFINITION "Display.Sprite"
#define LUA_CLEAR_SCREEN_DEFINITION "Display_ClearScreen"
#define LUA_UPDATE_SCREEN_DEFINITION "Display_UpdateScreen"
#define LUA_GET_FREE_MEMORY_DEFINITION "OS_GetFreeMemory"
#define LUA_GET_MEMORY_SIZE_DEFINITION "OS_GetMemorySize"
#define LUA_GET_FREE_HEAP_MEMORY_DEFINITION "OS_GetFreeHeapMemory"
#define LUA_GET_HEAP_MEMORY_SIZE_DEFINITION "OS_GetHeapMemorySize"
#define LUA_GET_CPU_TEMPERATURE_DEFINITION "OS_GetCPUTemperature"
#define LUA_GET_TIME_DEFINITION "OS_GetTime"
#define LUA_GET_LUA_HEAP_USAGE_DEFINITION "OS_GetLuaVMHeapMemoryUsage"
#define LUA_GET_USER_USERNAME_DEFINITION "OS_GetUserUsername"
#define LUA_GET_USER_PASSWORD_DEFINITION "OS_GetUserPassword"
#define LUA_OS_SLEEP_DEFINITION "OS_Sleep"
#define LUA_OS_RESTART_DEFINITION "OS_Restart"
#define LUA_OS_GET_KERNEL_VERSION_DEFINITION "OS_GetKernelVersion"
#define LUA_OS_SAVE_BIOS_CONFIGURATION_DEFINITION "OS_SaveBiosConfig"
#define LUA_OS_SAVE_SYSTEM_CONFIGURATION_DEFINITION "OS_SaveSystemConfig"
#define LUA_OS_SAVE_USER_CONFIGURATION_DEFINITION "OS_SaveUserConfig"
#define LUA_OS_SET_BIOS_CONFIG_INTEGER_KEY "OS_SetBiosConfigIntegerKey"
#define LUA_OS_SET_BIOS_CONFIG_INTEGER_KEY "OS_SetBiosConfigStringKey"
#define LUA_OS_SET_SYSTEM_CONFIG_INTEGER_KEY "OS_SetSystemConfigIntegerKey"
#define LUA_OS_SET_SYSTEM_CONFIG_INTEGER_KEY "OS_SetSystemConfigStringKey"
#define LUA_OS_SET_USER_CONFIG_INTEGER_KEY "OS_SetUserConfigIntegerKey"
#define LUA_OS_SET_USER_CONFIG_INTEGER_KEY "OS_SetUserConfigStringKey"

const char* ntpServer = "pool.ntp.org";
long gmtOffset_sec = -3 * 3600;  // UTC-3
const int daylightOffset_sec = 0;

StaticJsonDocument<1024> BiosConfiguration;
StaticJsonDocument<1024> SystemConfiguration;
StaticJsonDocument<1024> UserConfiguration;

struct Sprite;

// ===== Lua headers =====
extern "C" {
  #include "lua.h"
  #include "lauxlib.h"
  #include "lualib.h"
}

class LGFX : public lgfx::LGFX_Device {
  lgfx::Panel_ST7796 _panel_instance;
  lgfx::Bus_SPI _bus_instance;
  lgfx::Light_PWM _light_instance;

public:
  LGFX(void)
  {
    { // SPI
      auto cfg = _bus_instance.config();
      cfg.spi_host = SPI2_HOST;
      cfg.spi_mode = 0;
      cfg.freq_write = 80000000;
      cfg.freq_read  = 20000000;
      cfg.spi_3wire  = false;
      cfg.use_lock   = true;
      cfg.dma_channel = SPI_DMA_CH_AUTO;
      cfg.pin_sclk = 14;
      cfg.pin_mosi = 13;
      cfg.pin_miso = 12;
      cfg.pin_dc   = 9;
      _bus_instance.config(cfg);
      _panel_instance.setBus(&_bus_instance);
    }

    { // Painel ST7796
      auto cfg = _panel_instance.config();
      cfg.pin_cs  = 10;
      cfg.pin_rst = 11;
      cfg.pin_busy = -1;

      cfg.memory_width  = 320;
      cfg.memory_height = 480;
      cfg.panel_width   = 320;
      cfg.panel_height  = 480;

      cfg.offset_x = 0;
      cfg.offset_y = 0;

      cfg.readable   = false;
      cfg.invert     = true;    // ⚠️ deixar true
      cfg.rgb_order  = false;   // ⚠️ força modo BGR (a maioria dessas telas usa)
      cfg.dlen_16bit = false;
      cfg.bus_shared = true;

      _panel_instance.config(cfg);
    }

    { // Backlight
      auto cfg = _light_instance.config();
      cfg.pin_bl = 38;
      cfg.invert = false;
      cfg.freq   = 10000;
      cfg.pwm_channel = 7;
      _light_instance.config(cfg);
      _panel_instance.setLight(&_light_instance);
    }

    setPanel(&_panel_instance);
  }
};

LGFX tft;
LGFX_Sprite frame(&tft);

// ===== DIRTY RECT TRACKING =====
// Em vez de limpar/enviar a tela inteira (fillScreen + pushSprite completo) a
// cada ciclo Display_ClearScreen()/Display_UpdateScreen(), rastreamos apenas a
// região que efetivamente foi desenhada (por Sprite:draw() e Font:drawString())
// entre um clear e o update seguinte, e só tocamos essa região na PSRAM e no SPI.
struct DirtyRect {
  int x = 0, y = 0, w = 0, h = 0;
  bool valid = false;
};

DirtyRect frameDirtyAccum;  // o que foi desenhado NESTE frame (entre clear e update)
DirtyRect frameDirtyPrev;   // o que foi desenhado (e portanto ficou visível) no frame anterior
bool frameEverPushed = false;

void markDirty(int x, int y, int w, int h) {
  if (w <= 0 || h <= 0) return;

  if (!frameDirtyAccum.valid) {
    frameDirtyAccum.x = x;
    frameDirtyAccum.y = y;
    frameDirtyAccum.w = w;
    frameDirtyAccum.h = h;
    frameDirtyAccum.valid = true;
    return;
  }

  int x1 = min(frameDirtyAccum.x, x);
  int y1 = min(frameDirtyAccum.y, y);
  int x2 = max(frameDirtyAccum.x + frameDirtyAccum.w, x + w);
  int y2 = max(frameDirtyAccum.y + frameDirtyAccum.h, y + h);
  frameDirtyAccum.x = x1;
  frameDirtyAccum.y = y1;
  frameDirtyAccum.w = x2 - x1;
  frameDirtyAccum.h = y2 - y1;
}

void clampRectToScreen(int &x, int &y, int &w, int &h) {
  if (x < 0) { w += x; x = 0; }
  if (y < 0) { h += y; y = 0; }
  if (x + w > tft.width())  w = tft.width()  - x;
  if (y + h > tft.height()) h = tft.height() - y;
  if (w < 0) w = 0;
  if (h < 0) h = 0;
}

// TIME SYNC
void syncTime(const char* ssid, const char* password) {

  if (ssid != nullptr && password != nullptr &&
      strlen(ssid) > 0 && strlen(password) > 0) {

    WiFi.begin(ssid, password);
    Serial.println("Wifi Begin");

    unsigned long startAttemptTime = millis();

    while (WiFi.status() != WL_CONNECTED) {
      if (millis() - startAttemptTime > 60000) {
        Serial.println("ERR 0x005 - WiFi timeout");
        goto WIFI_FAIL;
      }
      delay(300);
    }

    Serial.println("Wifi Connected");

    configTime(gmtOffset_sec, daylightOffset_sec, ntpServer);

    struct tm timeinfo;
    startAttemptTime = millis();

    while (!getLocalTime(&timeinfo)) {
      if (millis() - startAttemptTime > 60000) {
        Serial.println("ERR 0x006 - NTP timeout");
        goto WIFI_FAIL;
      }
      delay(100);
    }

    Serial.println("Time Synchronized");

    WiFi.disconnect(true);
    WiFi.mode(WIFI_OFF);
    return;
  }

WIFI_FAIL:

  tft.print("ERR 0x004 - Couldn't start WIFI and configure time. Using 1/1/1970 - 00:00:00");
  Serial.println("ERR 0x004 - Couldn't start WIFI and configure time. Using 1/1/1970 - 00:00:00");

  WiFi.disconnect(true);
  WiFi.mode(WIFI_OFF);
  delay(3000);
}

static size_t luaHeapUsed = 0;
volatile bool luaRequestExit = false;

// ===== Alocador Lua usando PSRAM =====
void* lua_psram_alloc(void* ud, void* ptr, size_t osize, size_t nsize) {
  (void)ud;
  (void)osize; // NÃO confiamos mais nisso

  const size_t HEADER_SIZE = sizeof(size_t);

  // =========================
  // FREE
  // =========================
  if (nsize == 0) {
    if (ptr) {
      uint8_t* realPtr = (uint8_t*)ptr - HEADER_SIZE;
      size_t storedSize = *((size_t*)realPtr);

      if (luaHeapUsed >= storedSize)
        luaHeapUsed -= storedSize;
      else
        luaHeapUsed = 0;

      heap_caps_free(realPtr);
    }
    return NULL;
  }

  // =========================
  // REALLOC
  // =========================
  if (ptr) {
    uint8_t* realPtr = (uint8_t*)ptr - HEADER_SIZE;
    size_t oldSize = *((size_t*)realPtr);

    size_t futureUsed = luaHeapUsed - oldSize + nsize;

    if (futureUsed > LUA_HEAP_LIMIT) {
      Serial.println("ERR: Lua HEAP LIMIT REACHED");
      return NULL;
    }

    uint8_t* newRealPtr = (uint8_t*)heap_caps_realloc(realPtr, nsize + HEADER_SIZE,
                  MALLOC_CAP_SPIRAM | MALLOC_CAP_8BIT);

    if (!newRealPtr) return NULL;

    *((size_t*)newRealPtr) = nsize;
    luaHeapUsed = futureUsed;

    return newRealPtr + HEADER_SIZE;
  }

  // =========================
  // MALLOC
  // =========================
  if (luaHeapUsed + nsize > LUA_HEAP_LIMIT) {
    Serial.println("ERR: Lua HEAP LIMIT REACHED");
    return NULL;
  }

  uint8_t* realPtr = (uint8_t*)heap_caps_malloc(
    nsize + HEADER_SIZE,
    MALLOC_CAP_SPIRAM | MALLOC_CAP_8BIT
  );

  if (!realPtr) return NULL;

  *((size_t*)realPtr) = nsize;
  luaHeapUsed += nsize;

  return realPtr + HEADER_SIZE;
}

// KERNEL FUNCTIONS
bool saveBiosPreferences() {

  if (SD.exists("/boot/boot.json")) {
    SD.remove("/boot/boot.json");
  }

  File file = SD.open("/boot/boot.json", FILE_WRITE);
  if (!file) {
    Serial.println("ERR 0x101 - Couldn't open boot.json for writing.");
    return false;
  }

  if (serializeJson(BiosConfiguration, file) == 0) {
    Serial.println("ERR 0x102 - Failed to write boot.json.");
    file.close();
    return false;
  }

  file.close();
  Serial.println("Saved boot.json");
  return true;
}

bool saveSystemPreferences() {

  if (SD.exists("/usr/sys/general.json")) {
    SD.remove("/usr/sys/general.json");
  }

  File file = SD.open("/usr/sys/general.json", FILE_WRITE);
  if (!file) {
    Serial.println("ERR 0x201 - Couldn't open general.json for writing.");
    return false;
  }

  if (serializeJson(SystemConfiguration, file) == 0) {
    Serial.println("ERR 0x202 - Failed to write general.json.");
    file.close();
    return false;
  }

  file.close();
  Serial.println("Saved system.json");
  return true;
}

bool saveUserPreferences() {

  if (SD.exists("/usr/sys/user.json")) {
    SD.remove("/usr/sys/user.json");
  }

  File file = SD.open("/usr/sys/user.json", FILE_WRITE);
  if (!file) {
    Serial.println("ERR 0x301 - Couldn't open user.json for writing.");
    return false;
  }

  if (serializeJson(UserConfiguration, file) == 0) {
    Serial.println("ERR 0x302 - Failed to write user.json.");
    file.close();
    return false;
  }

  file.close();
  Serial.println("Saved user.json");
  return true;
}

struct Sprite {
  LGFX_Sprite spr;

  float rotation = 0.0f;   // graus
  int width = 0;
  int height = 0;

  Sprite() : spr(&tft) {
    spr.setColorDepth(16);
  }

  bool load(const char* caminho, int largura, int altura) {
    width = largura;
    height = altura;

    spr.setPsram(true);

    if (!spr.createSprite(largura, altura)) {
      tft.setTextColor(TFT_WHITE);
      tft.setCursor(5, 5);
      tft.printf("ERR 0x007 - Sprite creation failed at %s", caminho);
      while (1);
    }

    File f = SD.open(caminho);
    if (!f) {
      tft.setTextColor(TFT_WHITE);
      tft.setCursor(5, 5);
      tft.printf("ERR 0x008 - Couldn't open file at %s", caminho);
      while (1);
    }

    size_t tamanho = f.size();
    uint8_t* buffer = (uint8_t*)malloc(tamanho);
    if (!buffer) {
      tft.setTextColor(TFT_WHITE);
      tft.setCursor(5, 5);
      tft.printf("ERR 0x009 - Malloc failed");
      f.close();
      while (1);
    }

    f.read(buffer, tamanho);
    f.close();

    spr.drawPng(buffer, tamanho, 0, 0);
    free(buffer);

    return true;
  }

  void setRotation(float graus) {
    rotation = graus;
  }

  void draw(int x, int y) {
    if (rotation == 0.0f) {
      spr.pushSprite(&frame, x, y, 0x0000);
      markDirty(x, y, width, height);
      return;
    }

    spr.setPivot(width / 2, height / 2);
    frame.setPivot(x + width / 2, y + height / 2);

    spr.pushRotateZoom(&frame, rotation, 1.0f, 1.0f, 0x0000);

    // Com rotação a sprite pode ocupar mais área que width x height original.
    // Marca com margem de segurança usando a diagonal como lado do quadrado
    // que envolve qualquer ângulo de rotação.
    int diag = (int)ceilf(sqrtf((float)(width * width + height * height)));
    int cx = x + width / 2;
    int cy = y + height / 2;
    markDirty(cx - diag / 2, cy - diag / 2, diag, diag);
  }
};

// TIME
typedef struct {
    time_t timestamp;
} LuaTime;

// ===== EXPORTED FUNCTIONS =====
//int l_teste(lua_State* L) {
//  int numero = luaL_checkinteger(L, 1);
//  Serial.printf("[Lua] Teste: %d (core %d)\n", numero, xPortGetCoreID());
//  return 0;
//}

int l_endProgram(lua_State* L) {
  Serial.println("[Lua] Requesting VM shutdown");
  luaRequestExit = true;
  return 0;
}

int l_clearScreen(lua_State* L) {
  // Só precisamos apagar (voltar pra preto) a região que ficou visível no
  // frame anterior -- o resto da tela já está preto. Isso troca um
  // fillScreen() de 307KB por um fillRect() bem menor na maioria dos casos.
  if (frameDirtyPrev.valid) {
    frame.fillRect(frameDirtyPrev.x, frameDirtyPrev.y,
                    frameDirtyPrev.w, frameDirtyPrev.h, TFT_BLACK);
  } else {
    // Primeiro clear (ou sem histórico confiável ainda): limpa tudo por segurança.
    frame.fillScreen(TFT_BLACK);
  }

  frameDirtyAccum = DirtyRect();  // começa a acumular o que for desenhado neste novo frame
  return 0;
}

int l_updateScreen(lua_State* L){
  // A região que precisa ir pro display é a união de:
  //  - o que foi apagado agora (frameDirtyPrev, do clear deste ciclo)
  //  - o que foi desenhado agora (frameDirtyAccum)
  DirtyRect pushRect;

  if (frameDirtyPrev.valid && frameDirtyAccum.valid) {
    int x1 = min(frameDirtyPrev.x, frameDirtyAccum.x);
    int y1 = min(frameDirtyPrev.y, frameDirtyAccum.y);
    int x2 = max(frameDirtyPrev.x + frameDirtyPrev.w, frameDirtyAccum.x + frameDirtyAccum.w);
    int y2 = max(frameDirtyPrev.y + frameDirtyPrev.h, frameDirtyAccum.y + frameDirtyAccum.h);
    pushRect = { x1, y1, x2 - x1, y2 - y1, true };
  } else if (frameDirtyAccum.valid) {
    pushRect = frameDirtyAccum;
  } else if (frameDirtyPrev.valid) {
    pushRect = frameDirtyPrev;
  }

  if (!frameEverPushed) {
    // Primeiro update depois de ligar/trocar de app: manda a tela inteira
    // uma vez pra garantir que o display fique sincronizado com o frame.
    frame.pushSprite(0, 0);
    frameEverPushed = true;
  } else if (pushRect.valid) {
    clampRectToScreen(pushRect.x, pushRect.y, pushRect.w, pushRect.h);
    if (pushRect.w > 0 && pushRect.h > 0) {
      frame.setClipRect(pushRect.x, pushRect.y, pushRect.w, pushRect.h);
      frame.pushSprite(0, 0);
      frame.setClipRect(0, 0, frame.width(), frame.height());  // limpa o clip
    }
  }
  // Se pushRect não é válido e já houve push antes, nada mudou desde o
  // último update -- não há necessidade de gastar SPI reenviando a mesma coisa.

  frameDirtyPrev = frameDirtyAccum;
  frameDirtyAccum = DirtyRect();
  return 0;
}

// Sprites
static Sprite* checkSprite(lua_State* L, int index) {
  return (Sprite*)luaL_checkudata(L, index, LUA_SPRITE_DEFINITION);
}

int l_sprite_free(lua_State* L) {
  Sprite* spr = checkSprite(L, 1);
  spr->spr.deleteSprite();   // libera sprite interno
  return 0;
}

int l_sprite_constructor(lua_State* L) {
  const char* path = luaL_checkstring(L, 2);
  int w = luaL_checkinteger(L, 3);
  int h = luaL_checkinteger(L, 4);

  Sprite* spr = (Sprite*)lua_newuserdata(L, sizeof(Sprite));
  new (spr) Sprite();

  if (!spr->load(path, w, h)) {
    return luaL_error(L, "Sprite load failed");
  }

  luaL_getmetatable(L, LUA_SPRITE_DEFINITION);
  lua_setmetatable(L, -2);

  return 1;
}

int l_sprite_draw(lua_State* L) {
  Sprite* spr = checkSprite(L, 1);
  int x = luaL_checkinteger(L, 2);
  int y = luaL_checkinteger(L, 3);

  spr->draw(x, y);
  return 0;
}

int l_sprite_gc(lua_State* L) {
  Sprite* spr = checkSprite(L, 1);
  spr->~Sprite();
  return 0;
}

void registerSprite(lua_State* L) {

  // cria metatable do userdata
  luaL_newmetatable(L, LUA_SPRITE_DEFINITION);

  // __gc
  lua_pushcfunction(L, l_sprite_gc);
  lua_setfield(L, -2, "__gc");

  // métodos
  lua_newtable(L);

  lua_pushcfunction(L, l_sprite_draw);
  lua_setfield(L, -2, "draw");

  lua_pushcfunction(L, l_sprite_free);
  lua_setfield(L, -2, "free");

  lua_setfield(L, -2, "__index");

  lua_pop(L, 1);

  // ===== Tabela global Sprite =====
  lua_newtable(L);

  // metatable da tabela para suportar __call
  lua_newtable(L);
  lua_pushcfunction(L, l_sprite_constructor);
  lua_setfield(L, -2, "__call");
  lua_setmetatable(L, -2);

  lua_setglobal(L, "Sprite");
}

// OS FUNCTIONS
int l_getFreeMemory(lua_State* L){
  lua_pushinteger(L, ESP.getFreePsram());
  return 1; // number of returned values
}

int l_getMemorySize(lua_State* L){
  lua_pushinteger(L, ESP.getPsramSize());
  return 1;
}

int l_getFreeHeapMemory(lua_State* L){
  lua_pushinteger(L, ESP.getFreeHeap());
  return 1; // number of returned values
}

int l_getHeapMemorySize(lua_State* L){
  lua_pushinteger(L, ESP.getHeapSize());
  return 1;
}

int l_getCpuTemperature(lua_State* L){
    lua_pushnumber(L, temperatureRead());
    return 1;
}

int l_getLuaHeapUsage(lua_State* L){
  lua_pushnumber(L, luaHeapUsed);
  return 1;
}

int l_getUserUsername(lua_State* L){
  const char* username = UserConfiguration["username"];
  lua_pushstring(L, username);
  return 1;
}

int l_getUserPassword(lua_State* L){
  const char* password = UserConfiguration["password"];
  lua_pushstring(L, password);
  return 1;
}

int l_OS_Sleep(lua_State* L){
  delay(luaL_checkinteger(L, 1));
  return 1;
}

int l_OS_Restart(lua_State* L){
  esp_restart();
  return 0;
}

int l_OS_GetKernelVersion(lua_State* L){
  lua_pushstring(L, KERNEL_VERSION);
  return 1;
}

int l_OS_SetBiosConfigIntegerKey(lua_State* L){
    const char* key = luaL_checkstring(L, 1);
    int val = luaL_checkinteger(L, 2);

    BiosConfiguration[key] = val;

    return 0;
}

int l_OS_SetBiosConfigStringKey(lua_State* L){
    const char* key = luaL_checkstring(L, 1);
    const char* val = luaL_checkstring(L, 2);

    BiosConfiguration[key] = val;

    return 0;
}

int l_OS_SetSystemConfigIntegerKey(lua_State* L){
    const char* key = luaL_checkstring(L, 1);
    int val = luaL_checkinteger(L, 2);

    SystemConfiguration[key] = val;

    return 0;
}

int l_OS_SetSystemConfigStringKey(lua_State* L){
    const char* key = luaL_checkstring(L, 1);
    const char* val = luaL_checkstring(L, 2);

    SystemConfiguration[key] = val;

    return 0;
}

int l_OS_SetUserConfigIntegerKey(lua_State* L){
    const char* key = luaL_checkstring(L, 1);
    int val = luaL_checkinteger(L, 2);

    UserConfiguration[key] = val;

    return 0;
}

int l_OS_SetUserConfigStringKey(lua_State* L){
    const char* key = luaL_checkstring(L, 1);
    const char* val = luaL_checkstring(L, 2);

    UserConfiguration[key] = val;

    return 0;
}

int l_OS_SaveBiosConfig(lua_State* L){
  saveBiosPreferences();
  return 0;
}

int l_OS_SaveSystemConfig(lua_State* L){
  saveSystemPreferences();
  return 0;
}

int l_OS_SaveUserConfig(lua_State* L){
  saveUserPreferences();
  return 0;
}

int l_time_toString(lua_State* L) {
    LuaTime* t = (LuaTime*)luaL_checkudata(L, 1, "LuaTime");
    const char* format = luaL_optstring(L, 2, "%d/%m/%Y %H:%M:%S");

    struct tm* tm_info = localtime(&t->timestamp);

    char buffer[64];
    strftime(buffer, sizeof(buffer), format, tm_info);

    lua_pushstring(L, buffer);
    return 1;
}

int l_getTime(lua_State* L) {

    LuaTime* t = (LuaTime*)lua_newuserdata(L, sizeof(LuaTime));
    t->timestamp = time(nullptr);

    luaL_getmetatable(L, "LuaTime");
    lua_setmetatable(L, -2);

    return 1;
}

void registerTime(lua_State* L) {

    luaL_newmetatable(L, "LuaTime");

    lua_pushvalue(L, -1);
    lua_setfield(L, -2, "__index");

    lua_pushcfunction(L, l_time_toString);
    lua_setfield(L, -2, "toString");

    lua_pop(L, 1);
}

struct Font {

#pragma pack(push, 1)
    struct Glyph {
        uint32_t code;
        uint16_t atlas_x;
        uint16_t atlas_y;
        uint16_t w;
        uint16_t h;
        int16_t  xOff;
        int16_t  yOff;
        uint16_t advance;
    };
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
void loop() {
  // KERNEL
}

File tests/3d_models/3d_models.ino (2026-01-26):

#include <Arduino.h>
#include <LittleFS.h>
#include <SPI.h>
#include <LovyanGFX.hpp>
#include <math.h>
#include <vector>
#include <algorithm>
#include <cstdint>
#include <pgmspace.h>
// OTIMIZAR PERFORMANCE
// DIMINUIR O TAMANHO DOS HEADERS
#include "link.h"
#include "ganondorf.h"
#include "sky.h"

class LGFX : public lgfx::LGFX_Device {
  lgfx::Panel_ST7796 _panel_instance;
  lgfx::Bus_SPI _bus_instance;
  lgfx::Light_PWM _light_instance;
public:
  LGFX(void){
    { auto cfg = _bus_instance.config();
      cfg.spi_host = SPI2_HOST; cfg.spi_mode = 0;
      cfg.freq_write = 80000000; cfg.freq_read = 20000000;
      cfg.spi_3wire = false; cfg.use_lock = true; cfg.dma_channel = SPI_DMA_CH_AUTO;
      cfg.pin_sclk = 14; cfg.pin_mosi = 13; cfg.pin_miso = 12; cfg.pin_dc = 9;
      _bus_instance.config(cfg); _panel_instance.setBus(&_bus_instance);
    }
    { auto cfg = _panel_instance.config();
      cfg.pin_cs = 10; cfg.pin_rst = 11; cfg.pin_busy = -1;
      cfg.memory_width = 320; cfg.memory_height = 480;
      cfg.panel_width = 320; cfg.panel_height = 480;
      cfg.offset_x = 0; cfg.offset_y = 0;
      cfg.readable = false; cfg.invert = true; cfg.rgb_order = false;
      cfg.dlen_16bit = false; cfg.bus_shared = true;
      _panel_instance.config(cfg);
    }
    { auto cfg = _light_instance.config();
      cfg.pin_bl = 38; cfg.invert = false; cfg.freq = 10000; cfg.pwm_channel = 7;
      _light_instance.config(cfg); _panel_instance.setLight(&_light_instance);
    }
    setPanel(&_panel_instance);
  }
};
static LGFX tft;

// ---------------- 3D math ----------------
struct Vec3 { float x,y,z; };
struct Vec4 { float x,y,z,w; };
struct Mat4 { float m[4][4]; };

inline Vec4 mul(const Mat4 &M,const Vec4 &v){
  Vec4 r;
  r.x = M.m[0][0]*v.x + M.m[0][1]*v.y + M.m[0][2]*v.z + M.m[0][3]*v.w;
  r.y = M.m[1][0]*v.x + M.m[1][1]*v.y + M.m[1][2]*v.z + M.m[1][3]*v.w;
  r.z = M.m[2][0]*v.x + M.m[2][1]*v.y + M.m[2][2]*v.z + M.m[2][3]*v.w;
  r.w = M.m[3][0]*v.x + M.m[3][1]*v.y + M.m[3][2]*v.z + M.m[3][3]*v.w;
  return r;
}

inline Mat4 matIdentity(){ Mat4 I={}; for(int i=0;i<4;i++) for(int j=0;j<4;j++) I.m[i][j]=(i==j)?1.0f:0.0f; return I; }
inline Mat4 matTranslation(float tx,float ty,float tz){ Mat4 M=matIdentity(); M.m[0][3]=tx; M.m[1][3]=ty; M.m[2][3]=tz; return M; }
inline Mat4 matScale(float sx,float sy,float sz){ Mat4 M={}; M.m[0][0]=sx; M.m[1][1]=sy; M.m[2][2]=sz; M.m[3][3]=1.0f; return M; }
inline Mat4 matRotX(float a){ Mat4 M=matIdentity(); float c=cosf(a), s=sinf(a); M.m[1][1]=c; M.m[1][2]=-s; M.m[2][1]=s; M.m[2][2]=c; return M; }
inline Mat4 matRotY(float a){ Mat4 M=matIdentity(); float c=cosf(a), s=sinf(a); M.m[0][0]=c; M.m[0][2]=s; M.m[2][0]=-s; M.m[2][2]=c; return M; }
inline Mat4 matRotZ(float a){ Mat4 M=matIdentity(); float c=cosf(a), s=sinf(a); M.m[0][0]=c; M.m[0][1]=-s; M.m[1][0]=s; M.m[1][1]=c; return M; }
inline Mat4 matMul(const Mat4 &A,const Mat4 &B){ Mat4 R={}; for(int i=0;i<4;i++) for(int j=0;j<4;j++){ float s=0; for(int k=0;k<4;k++) s+=A.m[i][k]*B.m[k][j]; R.m[i][j]=s; } return R; }

Mat4 lookAt(const Vec3 &eye,const Vec3 &center,const Vec3 &up){
  Vec3 f={center.x-eye.x, center.y-eye.y, center.z-eye.z};
  float fl=sqrtf(f.x*f.x+f.y*f.y+f.z*f.z); if(fl==0) fl=1; f.x/=fl; f.y/=fl; f.z/=fl;
  Vec3 upn=up; float ul=sqrtf(upn.x*upn.x+upn.y*upn.y+upn.z*upn.z); if(ul==0) ul=1; upn.x/=ul; upn.y/=ul; upn.z/=ul;
  Vec3 s={ f.y*upn.z - f.z*upn.y, f.z*upn.x - f.x*upn.z, f.x*upn.y - f.y*upn.x };
  float sl = sqrtf(s.x*s.x+s.y*s.y+s.z*s.z); if(sl==0) sl=1; s.x/=sl; s.y/=sl; s.z/=sl;
  Vec3 u={ s.y*f.z - s.z*f.y, s.z*f.x - s.x*f.z, s.x*f.y - s.y*f.x };
  Mat4 M = matIdentity();
  M.m[0][0]=s.x; M.m[0][1]=s.y; M.m[0][2]=s.z; M.m[0][3]=-(s.x*eye.x + s.y*eye.y + s.z*eye.z);
  M.m[1][0]=u.x; M.m[1][1]=u.y; M.m[1][2]=u.z; M.m[1][3]=-(u.x*eye.x + u.y*eye.y + u.z*eye.z);
  M.m[2][0]=-f.x; M.m[2][1]=-f.y; M.m[2][2]=-f.z; M.m[2][3]=(f.x*eye.x + f.y*eye.y + f.z*eye.z);
  M.m[3][0]=0; M.m[3][1]=0; M.m[3][2]=0; M.m[3][3]=1;
  return M;
}

Mat4 perspective(float fovY,float aspect,float zn,float zf){
  float f = 1.0f / tanf(fovY * 0.5f);
  Mat4 P={};
  P.m[0][0] = f / aspect;
  P.m[1][1] = f;
  P.m[2][2] = (zf + zn) / (zn - zf);
  P.m[2][3] = (2.0f * zf * zn) / (zn - zf);
  P.m[3][2] = -1.0f;
  return P;
}

static Vec3 cross(const Vec3& a, const Vec3& b) {
  return Vec3(
    a.y * b.z - a.z * b.y,
    a.z * b.x - a.x * b.z,
    a.x * b.y - a.y * b.x
  );
}
// ---------------- Cube (cada cube sabe desenhar-se nos buffers) ----------------
struct Triangle { int v0,v1,v2; uint16_t color; };

struct Model {
  int vertCount;
  int triCount;
  const float* vertices;       // PROGMEM: x,y,z,x,y,z,...
  const unsigned int* indices; // PROGMEM: tripletas (v0,v1,v2,...)
  const float* uvs;            // PROGMEM: u,v,u,v,...
  const unsigned char* texture;// PROGMEM: RGBA bytes
  int texWidth;
  int texHeight;

  Vec3 position;
  Vec3 rotation;
  Vec3 scale;

  Model()
    : vertCount(0), triCount(0),
      vertices(nullptr), indices(nullptr), uvs(nullptr),
      texture(nullptr), texWidth(0), texHeight(0),
      position({0,0,0}), rotation({0,0,0}), scale({1,1,1})
  {}

  Mat4 getModelMatrix() const {
    Mat4 S = matScale(scale.x, scale.y, scale.z);
    Mat4 R = matMul(matRotZ(rotation.z), matMul(matRotY(rotation.y), matRotX(rotation.x)));
    Mat4 T = matTranslation(position.x, position.y, position.z);
    return matMul(T, matMul(R, S));
  }

  // Helpers to read from PROGMEM (works on ESP32 and AVR with included pgmspace.h)
  float readProgFloat(const float* addr) const {
    float v;
    memcpy_P(&v, addr, sizeof(float));
    return v;
  }
  unsigned int readProgUInt(const unsigned int* addr) const {
    unsigned int v;
    memcpy_P(&v, addr, sizeof(unsigned int));
    return v;
  }
  uint8_t readProgByte(const uint8_t* addr) const {
    return pgm_read_byte(addr);
  }

  // Convert RGBA (0-255) to RGB565 (uint16_t)
  static inline uint16_t rgba_to_rgb565(uint8_t r, uint8_t g, uint8_t b, uint8_t /*a*/) {
    return (uint16_t)((((uint16_t)r & 0xF8) << 8) | (((uint16_t)g & 0xFC) << 3) | (((uint16_t)b & 0xF8) >> 3));
  }

  // draw_fast signature matches Sphere::draw_fast
  void draw_fast(const Mat4 &MV, const Mat4 &MVP,
                 uint16_t *hrColor, int32_t *hrZ, int HR_W, int HR_H) const
  {
    if (vertCount <= 0 || triCount <= 0 || vertices == nullptr || indices == nullptr) return;

    const int QX = 16;
    const int QZ = 16;
    const int32_t X_SCALE = 1 << QX;
    const int32_t Z_SCALE = 1 << QZ;

    // 1) projetar e calcular atributos por vértice
    std::vector<Vec4> v_view(vertCount);
    std::vector<Vec4> v_clip(vertCount);
    std::vector<float> ndc_x(vertCount), ndc_y(vertCount), ndc_z(vertCount), wvals(vertCount), view_z(vertCount);
    std::vector<int32_t> px_fp(vertCount), pz_fp(vertCount);
    std::vector<int> py_i(vertCount);
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

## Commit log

2026-01-25 Create Repository
    [pcb_geral.kicad_pcb, pcb_geral.kicad_sch, pcb_upper.kicad_pcb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]
2026-01-26 New Day
    [acrylic_405d28f9-2327-4cdb-8ebe-de592a518881.blend, battery holder.STL, hinge1.stl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]
2026-01-26 A part of a new day
    [USB C full.stl, USB-A1VSXX.stl]
2026-01-26 Another Day of Work
    [3d print.blend, pcb_geral.kicad_pcb, pcb_geral_before_smd.kicad_pcb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]
2026-01-26 Edit design and added flat cable connector
2026-01-28 Another Day
    [3d print.blend]
2026-02-03 Removed PCB Upper
    [pcb_upper.kicad_pcb, pcb_upper.kicad_sch]
2026-02-05 Cart and BOM updated
    [BOM.csv, generalComponents.csv, powering specs.ods]
2026-02-05 Enhance README with features and case details
    Added detailed features and case description for Rian's MicroComputer.
2026-02-05 Added images
    [design.blend]
2026-02-06 Revise readme with additional PCB and keyboard details
    Updated the readme to include PCB and keyboard sections with images.
2026-02-06 Wiring Diagram
2026-02-07 Added Schematic to PCB General
    [pcb_geral.kicad_sch, teclado_matricial.kicad_pcb]
2026-02-08 Added Battery Holder to BOM and modified PCB schematic
    [BOM.csv, pcb_geral.kicad_pcb, pcb_geral.kicad_sch]
2026-02-12 Added Power Bank
    [BOM.csv, design.blend]
2026-02-12 Corrected PCB
    [design.blend, pcb_geral.kicad_pcb]
2026-02-12 Updated external wiring diagram
2026-02-12 Update Wiring Diagram
2026-02-12 Revise README with detailed project information
    Updated the README to include new features, case design, PCB details, BOM, and OS information.
2026-02-12 Revise README for Fiscion Razor32 details
    Updated the README to include additional details about the Fiscion Razor32, its features, case design, PCB information, BOM, OS, and planned apps.
2026-02-12 Revise README for Fiscion Razor32 details
    Updated the README file to include new information about the Fiscion Razor32 computer, including features, case design, PCB details, BOM, OS, and planned apps.
2026-02-26 Improved firmware
    [Box_Lower.stl, Box_Upper.stl, Hinges.stl]
2026-03-05 Improved keyboard schematic view
    [teclado_matricial.kicad_sch]
2026-03-05 Revise readme with updated features and OS details
    Updated the readme.md to include new features, OS details, and explaned how to install the firmware to the esp32
2026-03-05 Revise README with detailed project information
    Added the COM port and board explanation
2026-03-21 Updated cart and schematics
    [BOM.csv, pcb_geral.kicad_pcb, pcb_geral.kicad_sch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]
2026-03-22 Update powering specs
    [powering specs.ods]
2026-03-22 Updated cart
    [BOM.csv]
2026-03-22 Updated cart again
    [BOM.csv]
2026-03-22 Update case: Made the upper box close properly
    [Box_Upper.stl, design.blend]
2026-03-22 Update design
    [Box_Upper.stl, design.blend]
2026-05-18 BOM update with powerbank
    [BOM.csv]
2026-06-03 Added schematics to readme
    Updated readme.md to fix HTML encoding issues and improve formatting.
2026-06-03 Revise README for Fiscion Razor32 project
    Updated the README to include additional details about the Fiscion Razor32, including features, case design, PCB information, BOM, keyboard organization, OS and apps, and getting started instructions.
2026-06-06 unified pcbs
    [design.blend, pcbGeralComp.csv, pcbGeralCompPosition.csv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]
2026-06-07 pcb nets
    [razor32-B_Cu.gbr, razor32-B_Mask.gbr, razor32-B_Paste.gbr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]
2026-06-07 bom
    Updated readme.md to correct formatting and enhance clarity.
2026-08-25 Clean PCB
    [razor32-B_Cu.gbr, razor32-B_Mask.gbr, razor32-B_Paste.gbr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]
2026-08-25 images
    please return 2 commits for the 2 diode per key version
